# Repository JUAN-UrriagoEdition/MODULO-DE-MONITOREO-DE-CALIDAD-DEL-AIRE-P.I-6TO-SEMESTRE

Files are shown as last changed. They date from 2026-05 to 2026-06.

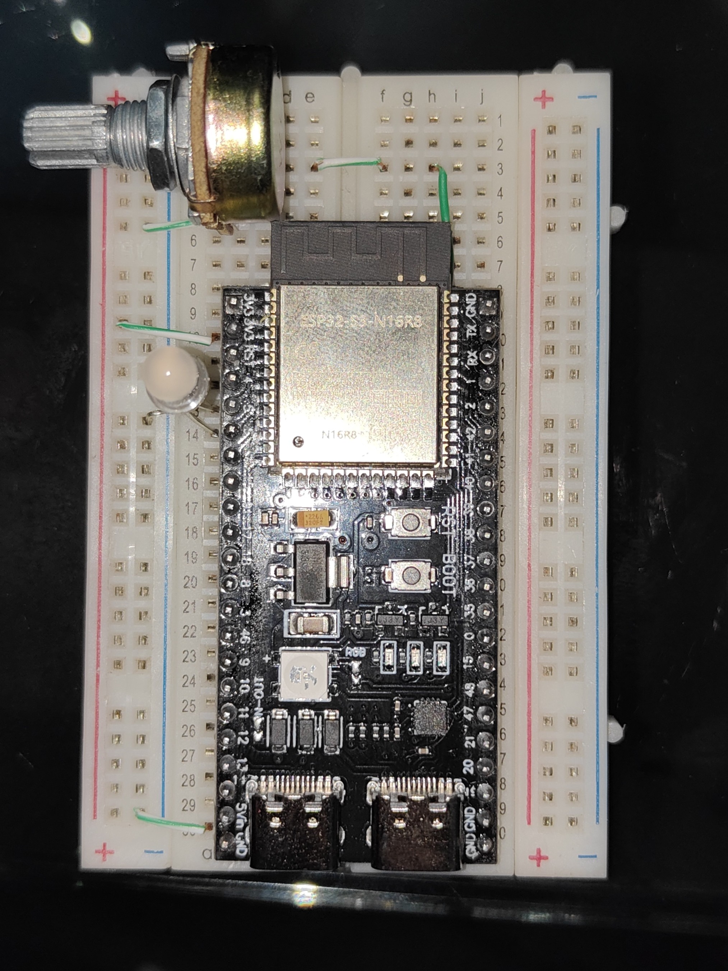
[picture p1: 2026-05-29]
Primer prototipo (Concepto).jpg

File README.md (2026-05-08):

# 🌬️ Estación Modular de Calidad del Aire (AQ)
### Módulo de Gases Electroquímicos — Ingeniería Electrónica, UCEVA 2026

<div align="center">






</div>

---

## 📋 Descripción General

Este repositorio documenta el **Módulo de Gases Electroquímicos** de la Estación Modular de Calidad del Aire (AQ), desarrollado como proyecto integrador de 6to semestre en la **Facultad de Ingeniería Electrónica de la Unidad Central del Valle del Cauca (UCEVA)**.

El módulo mide en tiempo real las concentraciones de **monóxido de carbono (CO)**, **dióxido de nitrógeno (NO₂)**, **CO₂ equivalente** y **compuestos orgánicos volátiles (COV)** tanto en entornos interiores como exteriores, publicando los datos a un dashboard web mediante WiFi.

> 📄 **[Descargar Informe Técnico Completo (WORD)](./ESTACION_AQ_ACTUALIZADO.docx)**
> 📄 **[Descargar Repositorio (.bat)](./Descargar_Repo_Monitor_de_Gases.bat)**

---

## 🎯 Motivación

La contaminación del aire representa uno de los mayores problemas de salud pública a nivel mundial. En el municipio de **Tuluá y el Valle del Cauca**, la ausencia de redes densas de monitoreo continuo limita la detección oportuna de episodios críticos de contaminación, especialmente en corredores viales de alto tráfico y en espacios interiores de instituciones educativas.

Los sistemas convencionales de monitoreo tienen costos de entre **USD 50.000 y 200.000** por estación. Este módulo propone una alternativa de **bajo costo** basada en sensores MEMS, con criterios rigurosos de instrumentación, calibración y validación.

---

## ⚙️ Arquitectura del Sistema

La cadena de instrumentación sigue el flujo completo:

```
Sensor MEMS → Filtro RC (fc ≈ 10.6 Hz) → Buffer LMV321 → ADC 12-bit ESP32-S3 → Procesamiento → WiFi → Hub → Dashboard
```

El sensor digital **CCS811** se conecta directamente por bus **I²C**, sin requerir acondicionamiento analógico externo.

---

## 🔬 Sensores y Componentes Principales

| Componente | Función | Interfaz |
|---|---|---|
| **SEN0564** (DFRobot) | CO — 5 a 5000 ppm | Analógica (0.4–2.0 V) |
| **SEN0574** (DFRobot) | NO₂ — 0.1 a 10 ppm | Analógica |
| **CCS811** (ScioSense) | CO₂eq + TVOC | Digital I²C |
| **ESP32-S3-WROOM-1U** | MCU, ADC 12-bit, WiFi | — |
| **LMV321** | Buffer seguidor de voltaje | — |
| **REF2033A** | Referencia de voltaje dual 3.3/1.65 V | — |
| **LP38692MP-3.3** | Regulador LDO 3.3 V | — |
| **LED RGB** | Indicación visual de calidad del aire | PWM |

---

## 📐 Diseño de Acondicionamiento Analógico

- **Filtro RC pasabajas** de primer orden: `R = 10 kΩ`, `C = 1.5 µF` → `fc ≈ 10.6 Hz`
- **Buffer LMV321** en configuración seguidor unitario (ganancia 1) para desacoplar la impedancia del ADC
- **Referencia REF2033A** con baja deriva térmica para estabilidad en la conversión ADC
- **ADC SAR de 12 bits** del ESP32-S3: resolución teórica de `≈ 0.806 mV/bit`
- **Sobremuestreo y promediado** (N = 32–64 muestras) para mejorar la resolución efectiva (ENOB ≥ 11 bits)

---

## 💡 Indicación Visual

El LED RGB indica el nivel de calidad del aire mediante colores controlados por PWM (5 kHz, 8 bits):

| Color | Estado | Umbral |
|---|---|---|
| 🟢 Verde | Limpio | < 40% de escala |
| 🟡 Ámbar | Advertencia | 40–70% de escala |
| 🔴 Rojo | Crítico | > 70% de escala |

---

## 📡 Formato de Mensajes JSON (Contrato de Datos)

El módulo publica al hub central mensajes con la siguiente estructura mínima:

```json
{
  "module": "gas_module_01",
  "environment": "indoor",
  "location": "UCEVA - Aula 201",
  "ts": 1745000000,
  "metrics": {
    "co_ppm": 1.2,
    "no2_ppm": 0.05,
    "eco2_ppm": 520,
    "tvoc_ppb": 35,
    "quality": "ok",
    "temp_comp": 24.5,
    "rh_comp": 58.0
  }
}
```

---

## 🔄 Estados del Firmware

| Estado | Descripción |
|---|---|
| `warmup` | Calentamiento inicial del sensor (< 2 min) |
| `ok` | Operación normal |
| `fault` | Sensor desconectado o señal fuera de rango |
| `saturation` | Señal en los extremos del rango ADC |
| `suspect` | Alta variabilidad o lecturas inconsistentes |

---

## 📦 Lista de Materiales (BOM)

Los componentes fueron adquiridos mediante el pedido **Mouser N.° 279751168** (enviado el 21 de abril de 2026). El costo total del pedido fue de aproximadamente **USD 48** más aranceles de importación colombianos.

Los sensores SEN0564, SEN0574 y el LED RGB se adquirieron de forma local/separada.

---

## 🧪 Pruebas y Criterios de Aceptación

| ID | Prueba | Criterio |
|---|---|---|
| CP01 | Rango analógico SEN0564 (CO) | V_out varía de forma monotónica en 0.4–2.0 V |
| CP04 | Respuesta del filtro RC | Atenuación a fc = −3 dB ± 1 dB; a 10·fc ≥ −20 dB |
| CP06 | Publicación de mensajes JSON | ≥ 5 mensajes válidos en 5 minutos |
| CP07 | Estado warmup al encender | `quality = warmup` durante ≥ 60 s |
| CP08 | Estado fault ante desconexión | `quality = fault` en ≤ 3 ciclos de publicación |

---

## 👥 Equipo

| Nombre | Código |
|---|---|
| David Ortega Ruiz | 240232001 |
| Juan Fernando Urriago Hernández | 240232002 |
| Sergio Peñaranda Agudelo | 240232004 |
| Miguel Ángel Parra Gutiérrez | 240232013 |

**Asignatura integradora:** Instrumentación I  
**Docente:** Álvaro Hernando Salazar Victoria  
**Facultad de Ingeniería Electrónica — UCEVA, 2026**

---

## 📚 Referencias Clave

- Mead et al. (2013) — *Atmospheric Environment* — Redes urbanas con sensores electroquímicos
- Kumar et al. (2015) — *Environment International* — Sensores de bajo costo para calidad del aire
- Spinelle et al. (2015) — *Sensors and Actuators B* — Calibración en campo con MLR
- Zimmerman et al. (2018) — *Atmospheric Measurement Techniques* — Calibración con Random Forest

---

> 📄 **[Descargar Informe Técnico Completo (PDF)](./ESTACIÓN_MODULAR_DE_CALIDAD_DEL_AIRE.pdf)**

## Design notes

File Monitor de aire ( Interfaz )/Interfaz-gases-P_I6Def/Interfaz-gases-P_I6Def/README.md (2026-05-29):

# Interfaz-gases P.I6Def — Monitor de Gases ESP32-S3
## Requisitos
- NetBeans IDE 17+ con soporte para proyectos Java Free-Form / Ant
- JDK 17 o superior
- ESP32-S3 corriendo el firmware P_I6Def_ESP32S3_fixed.ino
  (protocolo serial 115200 baud: CO:<ppm>,NO2:<ppm>,CO2:<ppm>,VOC:<ppb>)

---

## Abrir en NetBeans (primera vez)

1. File → Open Project → seleccionar esta carpeta (Interfaz-gases-P_I6Def)
2. NetBeans detecta el build.xml de Ant automáticamente
3. **Run → Build Project (F11)**
   - Ant descarga jSerialComm-2.11.0.jar automáticamente a lib/
   - Si no hay internet: descarga el JAR manualmente de
     https://github.com/Fazecast/jSerialComm/releases
     y cópialo a lib/jSerialComm-2.11.0.jar
4. **Run → Run Project (F6)** para ejecutar la GUI

---

## Si NetBeans no reconoce el classpath

Project Properties → Libraries → Add JAR/Folder → selecciona:
  lib/jSerialComm-2.11.0.jar

---

## Protocolo Serial (ESP32-S3 → Java)

Líneas de datos (parseadas por la GUI):
  CO:85.30,NO2:0.042,CO2:512.0,VOC:180.0

Líneas de log (ignoradas por la GUI, empiezan con #):
  # [OK] CCS811 listo
  # t=5s  Vco=1.234V  Vno2=2.987V

Baud rate: 115200
Terminador: \n

---

## Funciones de la GUI

- Indicadores circulares (gauges) con colores por nivel de alerta
- Gráficas históricas de los últimos 60 segundos
- Selector de puerto serial con botón de refresco
- Modo DEMO (simula datos sin hardware conectado)
- Estado de conexión en tiempo real

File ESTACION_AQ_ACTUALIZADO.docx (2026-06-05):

ESTACIÓN MODULAR DE CALIDAD DEL AIRE (AQ) PARA INTERIOR Y EXTERIOR

[MÓDULO DE GASES ELECTROQUÍMICOS]

David Ortega Ruiz — Código: 240232001

Miguel Ángel Parra Gutiérrez — Código: 240232013

Sergio Peñaranda Agudelo — Código: 240232004

Juan Fernando Urriago Hernández — Código: 240232002

Trabajo presentado para la asignatura integradora: Instrumentación I

Docente: SALAZAR VICTORIA ALVARO HERNANDO

Asignaturas que se articulan:

Administración — HERNANDEZ TRUJILLO YANIER ALBERTO

Electrónica Digital II — ARENAS HOYOS SERGIO ANDRES

Sistemas & Señales — LOZADA DAS DORES ANGEL JOSE

Circuitos Electrónicos II — PEREZ HERNANDEZ JAIME

Comunicaciones I — SALDARRIAGA VILLAFAÑE HAEDERS

Facultad de Ingeniería — Ingeniería Electrónica

Unidad Central del Valle del Cauca — 2026

# 1. INTRODUCCIÓN

## 1.1 Contexto del Problema (Calidad del Aire Indoor/Outdoor)

La contaminación atmosférica representa uno de los mayores problemas de salud pública a nivel mundial. Según la Organización Mundial de la Salud (OMS), alrededor de 7 millones de personas mueren prematuramente cada año como consecuencia directa de la exposición a aire contaminado en entornos tanto interiores como exteriores. En las zonas urbanas latinoamericanas, incluyendo el departamento del Valle del Cauca (Colombia), la combinación de emisiones vehiculares, actividad industrial y quema de biomasa genera concentraciones significativas de monóxido de carbono (CO) y dióxido de nitrógeno (NO₂), que en episodios de alta contaminación pueden superar los valores guía de la OMS y los límites establecidos por la Resolución 2254 de 2017 del MADS (Kumar et al., 2015).

Los sistemas de monitoreo convencionales tienen costos de adquisición e instalación en el rango de USD 50.000–200.000 por estación, lo que impide la construcción de redes de medición de alta densidad espacial. Esta limitación ha impulsado el desarrollo de sensores de bajo costo —electroquímicos y de óxidos metálicos semiconductores (MOX) tipo MEMS— capaces de proporcionar datos representativos cuando se diseñan e implementan con criterios rigurosos de instrumentación, calibración y validación de datos (Lewis & Edwards, 2016; Mead et al., 2013).

En el contexto local del municipio de Tuluá y sus alrededores, la carencia de redes densas de monitoreo continuo limita la capacidad de detección oportuna de episodios críticos de contaminación, especialmente en corredores viales de alto tráfico y en espacios interiores de instituciones educativas.

## 1.2 Motivación del Módulo

El módulo de gases es uno de los componentes centrales de la estación modular AQ propuesta. Los sensores seleccionados —SEN0564 para CO y SEN0574 para NO₂, ambos con tecnología MEMS de DFRobot— generan señales de voltaje analógico compatibles con el ADC del ESP32-S3-WROOM-1U directamente. El circuito de acondicionamiento incluye filtros RC pasabajas y seguidores de voltaje (LMV321) para garantizar lecturas estables. Los gases elegidos —CO y NO₂— son contaminantes de alta relevancia para la salud pública en entornos urbanos colombianos.

Adicionalmente, el módulo incorpora el sensor digital CCS811 para medición complementaria de CO₂ equivalente y COV (Compuestos Orgánicos Volátiles), comunicado por bus I²C con el ESP32-S3-WROOM-1U. Esta combinación permite una caracterización más completa de la calidad del aire interior.

# 2. PLANTEAMIENTO DEL PROBLEMA Y OBJETIVOS

## 2.1 Problema a Resolver

La ausencia de redes de monitoreo continuo y de bajo costo para gases contaminantes en las zonas urbanas del Valle del Cauca impide la detección, cuantificación y alerta oportuna de episodios de contaminación del aire en tiempo real. En espacios interiores prácticamente no existe monitoreo de CO y NO₂, pese a que diversas fuentes pueden generar concentraciones superiores a los valores guía de la OMS durante periodos prolongados.

El reto técnico central de este módulo es integrar los sensores MEMS SEN0564 y SEN0574 con el microcontrolador ESP32-S3-WROOM-1U, garantizando un acondicionamiento analógico adecuado (filtrado, buffer de impedancia), adquisición confiable por ADC de 12 bits, y comunicación inalámbrica de datos hacia el hub central del sistema AQ.

## 2.2 Objetivo General

Diseñar e implementar una estación modular AQ capaz de medir variables ambientales y contaminantes gaseosos (CO y NO₂), procesarlas digitalmente y publicarlas en un dashboard web con histórico y alertas, demostrando criterios de diseño de instrumentación (rango, resolución, filtrado, calibración y manejo de error), operando en interior y exterior.

## 2.3 Objetivos Específicos

- Seleccionar y caracterizar los sensores SEN0564 (CO), SEN0574 (NO₂) y CCS811 (CO₂eq/COV) para calidad del aire.
- Diseñar el acondicionamiento analógico con filtros RC y buffers LMV321 para llevar las señales al rango del ADC del ESP32-S3-WROOM-1U.
- Publicar datos mediante un esquema de comunicación IoT usando un formato estándar de mensajes JSON.
- Integrar todos los módulos en un sistema común (hub) con almacenamiento, alertas y dashboard web.
- Realizar calibración mínima y reportar un presupuesto básico de error.

# 3. ESTADO DEL ARTE

## 3.1 Referentes

### Sensores electroquímicos en redes urbanas densas (Mead et al., 2013)

El trabajo de Mead et al. (2013), publicado en Atmospheric Environment, es uno de los estudios fundacionales del monitoreo urbano de bajo costo. El equipo de la Universidad de Cambridge desplegó 14 nodos equipados con sensores electroquímicos para CO, NO₂ y O₃, y los comparó durante varios meses con analizadores de referencia certificados. Los resultados demostraron que los sensores electroquímicos son viables para detectar gradientes espaciales y temporales de contaminación, pero presentan sensibilidades cruzadas significativas a la temperatura, la humedad relativa y a gases interferentes. El estudio concluye que la compensación de temperatura y humedad en el firmware es indispensable para lograr coeficientes de correlación r² > 0.80 respecto a los instrumentos de referencia.

### Gestión de calidad del aire urbana con sensores de bajo costo (Kumar et al., 2015)

Kumar et al. (2015) realizaron una revisión exhaustiva del estado del arte en sistemas de sensores de bajo costo para monitoreo de calidad del aire urbana. Analizaron comparativamente las tecnologías disponibles —electroquímica, MOX, fotoionización (PID) y NDIR— en términos de sensibilidad, deriva temporal, efecto de la humedad relativa, costo y complejidad de calibración. Sus conclusiones identifican que la principal barrera de adopción de sensores de bajo costo no es la sensibilidad inicial, sino la deriva de calibración a largo plazo y el efecto de la humedad relativa sobre la respuesta del sensor.

### Calibración en campo de sensores de bajo costo (Spinelle et al., 2015)

Spinelle et al. (2015) publicaron los resultados de la calibración en campo de sensores de bajo costo para O₃ y NO₂ frente a instrumentos de referencia. Los experimentos demostraron que la incorporación de temperatura y humedad relativa como covariables en modelos de regresión lineal múltiple mejora el coeficiente de determinación R² de valores entre 0.30–0.50 a valores superiores a 0.85.

### Calibración con Random Forest (Zimmerman et al., 2018)

Zimmerman et al. (2018) propusieron el uso de modelos de aprendizaje automático (Random Forest) para la calibración de sensores de bajo costo de NO₂ y CO, demostrando que los modelos de bosque aleatorio logran R² superiores a 0.90 para NO₂ y reducciones del error cuadrático medio de hasta 40% respecto a la regresión lineal múltiple.

### Comparación de microsensores con métodos de referencia — EuNetAir (Borrego et al., 2016)

Borrego et al. (2016) presentaron el ejercicio comparativo europeo EuNetAir, donde sensores de bajo costo fueron evaluados simultáneamente contra instrumentos de referencia certificados en múltiples sitios de Europa. Los resultados confirmaron que los sensores de CO presentan el mejor desempeño relativo sin compensación ambiental, mientras que NO₂ muestra mayor variabilidad y dependencia de la humedad.

## 3.2 Comparación de Enfoques

Referente | Tecnología sensor | Acondicionamiento | Comunicación | Métrica de validación
Mead et al. (2013) | Electroquímica | TIA + offset + RC | ZigBee/3G | R² = 0.70–0.85 (con comp. T/HR)
Kumar et al. (2015) | MOX + electroquímica | Div. resistivo + buffer | WiFi/GSM | Identifica deriva y efecto HR
Spinelle et al. (2015) | Electroquímica (O₃/NO₂) | Buffer + MLR (T,HR) | USB/LAN | R² > 0.85 con MLR
Zimmerman et al. (2018) | MOX + electroquímica | Buffer + RF-ML | Ethernet | R² > 0.90 con Random Forest
Borrego et al. (2016) | Electroquímica/MOX | TIA + buffer | LAN | CO mejor desempeño sin comp.
Lewis & Edwards (2016) | Múltiples | Variados | Variados | r² ≥ 0.70, sesgo < 30%

## 3.3 Lecciones Aprendidas

- Compensación de temperatura y humedad es indispensable: todos los referentes señalan que T y HR afectan significativamente las lecturas. El módulo solicitará estos valores al módulo meteorológico del sistema y los incluirá en el campo metrics del mensaje JSON.
- El buffer de impedancia (seguidor de voltaje con LMV321) es la etapa crítica para la lectura confiable de los sensores MEMS tipo SEN0564 y SEN0574, cuya salida analógica requiere aislamiento de la carga del ADC.
- Priorizar el canal de CO para validación inicial: los sensores de CO presentan el mejor desempeño relativo sin compensación ambiental.

# 4. MARCO TEÓRICO

## 4.1 Conceptos de Calidad del Aire Relevantes al Módulo

La calidad del aire se evalúa cuantitativamente mediante la concentración de contaminantes primarios y secundarios expresada en µg/m³ o ppm (partes por millón en volumen). Para los gases del módulo, los valores guía de la OMS (2021) y los límites de la normativa colombiana (Resolución 2254/2017) son:

Gas | Valor guía OMS (2021) | Límite Colombia (Res. 2254/2017) | Fuentes principales | Efecto en salud
CO | 4 mg/m³ (24h); 35 mg/m³ (1h) | 30 mg/m³ (1h); 10 mg/m³ (8h) | Combustión incompleta (vehículos, estufas) | Forma COHb; reduce transporte O₂
NO₂ | 25 µg/m³ (24h); 200 µg/m³ (1h) | 200 µg/m³ (1h); 100 µg/m³ (24h) | Combustión a alta T, motores, industria | Inflamación bronquial; precursor O₃
CO₂eq/COV | N/A (indicador interior) | N/A | Actividad humana, materiales sintéticos | Calidad del aire interior; síntomas de SBS

## 4.2 Principio Físico/Químico de los Sensores

### SEN0564 — Sensor CO (DFRobot, tecnología MEMS)

El SEN0564 es un sensor de monóxido de carbono basado en tecnología MEMS (Micro-Electro-Mechanical Systems) con salida analógica de voltaje. Internamente emplea un elemento semiconductor calentado que varía su resistencia eléctrica en presencia de CO. A diferencia de los módulos MQ-7 tradicionales, el SEN0564 incorpora el circuito de acondicionamiento interno, entregando directamente una señal de voltaje proporcional a la concentración de CO en el rango de 5 a 5000 ppm. La salida opera entre 1V (aire limpio) y 3.5 V (concentración máxima).

### SEN0574 — Sensor NO₂ (DFRobot, tecnología MEMS)

El SEN0574 es un sensor de dióxido de nitrógeno también basado en tecnología MEMS con salida analógica de voltaje, diseñado para detectar concentraciones de NO₂ en el rango de 0.1 a 10 ppm. Su principio de operación se basa en la variación de conductancia de un material semiconductor en función de la concentración del gas objetivo. La señal de salida es analógica y varía con la concentración de NO₂, con respuesta que depende de la temperatura y la humedad relativa del entorno, por lo que se requiere compensación en firmware.

### CCS811 — Sensor digital CO₂eq/COV

El CCS811 es un sensor digital de calidad del aire interior que mide CO₂ equivalente (eCO₂) y Compuestos Orgánicos Volátiles (COV o TVOC). Se comunica con el ESP32-S3-WROOM-1U mediante bus I²C, simplificando la integración al no requerir conversión analógico-digital ni circuito de acondicionamiento externo. Incorpora un microcontrolador interno que ejecuta el procesamiento de señal y entrega directamente los valores en ppm de eCO₂ y ppb de TVOC.

## 4.3 Conceptos Base de Instrumentación del Módulo

El seguidor de voltaje (buffer) implementado con el amplificador LMV321 cumple la función de adaptar la impedancia de salida de los sensores SEN0564 y SEN0574 a la impedancia de entrada del ADC del ESP32-S3-WROOM-1U. Sin este buffer, la carga capacitiva y resistiva del ADC puede alterar la lectura de los sensores, especialmente durante el proceso de muestreo del convertidor SAR. El LMV321 opera en configuración de seguidor unitario (ganancia 1), con rail-to-rail de salida, lo que lo hace adecuado para señales que cubren todo el rango de alimentación de 3.3V.

## 4.4 Fundamentos de Filtros Analógicos

Los sensores MEMS de gases presentan dinámicas lentas de respuesta: el tiempo de respuesta t₉₀ del SEN0564 y SEN0574 es del orden de decenas de segundos. Esto implica que el contenido frecuencial de la señal de interés está por debajo de fracciones de Hz. Todo contenido espectral por encima de esta frecuencia corresponde a ruido eléctrico y debe atenuarse antes de la conversión ADC.

Se implementa un filtro RC de primer orden pasivo a la salida de cada sensor, antes del buffer LMV321. Con R = 10 kΩ y C = 1.5 µF, la frecuencia de corte resulta fc ≈ 10.6 Hz. Esta topología conserva la dinámica lenta del gas y atenúa perturbaciones rápidas asociadas al ruido, siendo suficiente para una etapa de adquisición de baja velocidad como la de este módulo.

# 5. REQUISITOS Y CRITERIOS DE ACEPTACIÓN

## 5.1 Requisitos Funcionales

ID | Requisito Funcional | Prioridad
RF-01 | El módulo medirá CO con el sensor SEN0564 (DFRobot MEMS) en el rango 5–5000 ppm mediante señal analógica de voltaje y ADC de 12 bits del ESP32-S3-WROOM-1U. | Alta
RF-02 | El módulo medirá NO₂ con el sensor SEN0574 (DFRobot MEMS) en el rango 0.1–10 ppm mediante señal analógica de voltaje y ADC. | Alta
RF-03 | El módulo leerá CO₂eq y TVOC del sensor digital CCS811 mediante bus I²C con el ESP32-S3-WROOM-1U. | Media
RF-04 | El circuito de acondicionamiento garantizará que la señal de salida de todos los canales analógicos se encuentre en el rango 0.1–3.3 V para el ADC. | Alta
RF-05 | Cada canal analógico contará con un filtro RC pasabajas (fc ≈ 10.6 Hz) y buffer LMV321 antes de la entrada ADC. | Alta
RF-06 | El ADC del ESP32-S3-WROOM-1U adquirirá señales a una tasa de muestreo fs ≥ 10 Hz con resolución de 12 bits. | Media
RF-09 | El módulo operará en dos modos: indoor (publicación cada 10–30 s) y outdoor (publicación cada 30–60 s). | Media
RF-10 | El firmware gestionará los estados del sensor: warmup, ok, fault, saturation, suspect. | Alta
RF-11 | El sistema implementará indicación visual de nivel de contaminación mediante LED RGB: verde (limpio), ámbar (advertencia) y rojo (crítico). | Media

## 5.2 Requisitos No Funcionales

ID | Requisito | Valor objetivo
RNF-01 | Frecuencia de publicación — indoor | Cada 10–30 s
RNF-02 | Frecuencia de publicación — outdoor | Cada 30–60 s (con promedio de ventana extendida)
RNF-03 | Tiempo de warm-up hasta primer dato ok | < 5 minutos desde el encendido
RNF-04 | Tensión de alimentación del módulo | 5 V entrada y sensores; 3.3 V regulado (LP38692MP-3.3) para ESP32-S3-WROOM-1U, LMV321
RNF-05 | Rango de temperatura de operación outdoor | 0°C a +50°C
RNF-06 | ENOB efectivo mínimo con promediado | ≥ 11 bits (N = 64 muestras, oversampling)
RNF-07 | Comportamiento ante pérdida de conectividad | Almacenamiento local y reenvío al reconectar
RNF-09 | Protección contra saturación del ADC | El acondicionamiento analógico mantiene la señal dentro del rango 0–3.3 V

## 5.3 Criterios de Aceptación Preliminares

- Acondicionamiento analógico: la señal de salida permanecerá entre 0.1 V y 3.3 V para todas las concentraciones de gas dentro del rango nominal del sensor.
- Filtro analógico: se demostrará una atenuación ≥ 6 dB a una frecuencia 10 veces superior a la fc de diseño.
- Publicación de mensajes: el módulo publicará al menos 5 mensajes JSON válidos al hub durante una sesión de prueba de 5 minutos.
- Indicación visual: el LED RGB cambiará de color de forma consistente con el nivel de contaminación detectado por el potenciómetro de simulación o el sensor real.

6. SELECCIÓN Y CARACTERIZACIÓN DEL SENSOR

## 6.1 Principio de Medición

El módulo de gases emplea tres sensores con principios de medición complementarios. El SEN0564 y SEN0574 (DFRobot) utilizan tecnología MEMS con salida analógica de voltaje, mientras que el CCS811 emplea tecnología digital con interfaz I²C.

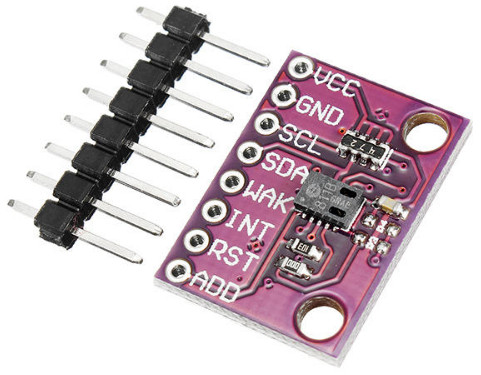
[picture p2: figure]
CJMCU-811 - RevSpace
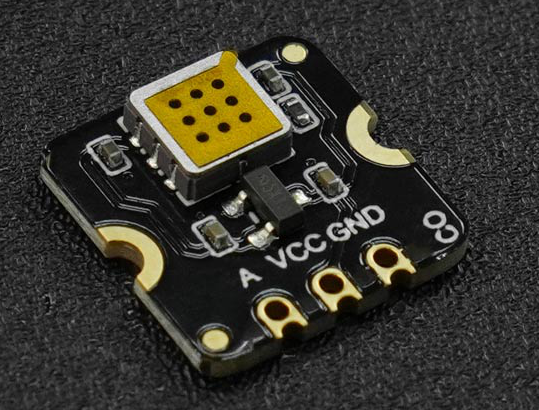
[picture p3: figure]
SEN0564 - Sigma Electrónica

Ilustración 3 CSS 811 - SENSOR DE GASES VOLATILES

Ilustración 2 SEN0574 - SENSOR NO2

Ilustración 1 SEN0564 - SENSOR DE CO

## 6.2 Rango Esperado y Sensibilidad

Parámetro | SEN0564 (CO — MEMS) | SEN0574 (NO₂ — MEMS) | CCS811 (CO₂eq/COV — digital)
Gas objetivo | CO | NO₂ | CO₂ equivalente + TVOC
Principio físico | Semiconductor MEMS — salida analógica | Semiconductor MEMS — salida analógica | MOx — salida digital I²C
Rango de medición | 5–5000 ppm (CO) | 0.1–10 ppm (NO₂) | 400–29206 ppm eCO₂; 0–32768 ppb TVOC
Señal de salida | Voltaje analógico 1.0–3.5 V | Voltaje analógico (proporcional) | Digital I²C (registros de 16 bits)
Tensión de operación | 5 V | 5 V | 1.8–3.6 V (I²C a 3.3 V)
Temperatura de operación | 0°C a +50°C | 0°C a +50°C | −40°C a +85°C
Tiempo de respuesta | < 30 s | < 30 s | < 60 s (modo 1s)
Tiempo de warm-up | 5 min | 5 min | 20 min (primer arranque); 60 s (subsiguientes)
Interferencias | Alcohol, LPG, humo | CO, O₃, H₂S | Temperatura, humedad

## 6.3 Fuentes de Error e Interferencias

- Temperatura y humedad (todos los sensores): la sensibilidad de los sensores MEMS varía con estas dos variables. Se implementará compensación mediante los datos del módulo meteorológico del sistema AQ.
- Interferencias cruzadas del SEN0574: el sensor de NO₂ puede ser afectado por presencia de CO, O₃ y H₂S en concentraciones elevadas.
- Warm-up del CCS811: el sensor requiere un tiempo de calentamiento de 20 minutos en el primer arranque para estabilizar su respuesta. El firmware reportará estado warmup durante este periodo.

## 6.4 Consideraciones Indoor vs Outdoor

Aspecto | Indoor (Interior) | Outdoor (Exterior)
Conc. típicas CO | 1–10 ppm (cocina, calefacción) | 0.1–5 ppm (tráfico urbano)
Conc. típicas NO₂ | 0.05–0.5 ppm (cocina gas, tráfico exterior) | 0.05–0.5 ppm (urbano); >1 ppm (vial alta densidad)
Efecto de humedad | Más estable, HR típica 40–60% | HR puede llegar a 90–100%
Temperatura | Más estable (18–28°C) | Mayor rango (5–40°C); exposición solar posible
Umbrales de alerta | Más sensibles (OMS ×1) | Umbrales según normativa outdoor (OMS/EPA)
Frecuencia de publicación | Cada 10–30 s | Cada 30–60 s (promedio ventana extendida)
Acciones outdoor | N/A | Caja con protección IP54; rejillas anti-insectos; shield solar

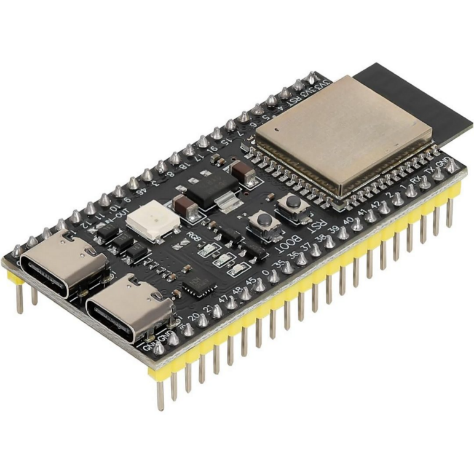
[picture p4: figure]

Ilustración 4 ESP32-S3 - Microcontrolador del módulo. Incluye ADC de 12 bits, WiFi, Bluetooth y soporte para FreeRTOS

# 7. ARQUITECTURA DEL SISTEMA Y DIAGRAMA DE BLOQUES

## 7.1 Diagrama de Bloques del Módulo

La arquitectura del módulo sigue la cadena de instrumentación completa: los sensores SEN0564 y SEN0574 generan señales analógicas de voltaje que pasan por un filtro RC pasabajas (R = 10 kΩ, C = 1.5 µF), luego por un buffer seguidor de voltaje (LMV321), y finalmente ingresan a los pines ADC del ESP32-S3-WROOM-1U. El sensor CCS811 se conecta directamente por I²C.

Ilustración 5 Diagrama de bloques del módulo de gases — Sensor → Filtro RC → Buffer LMV321 → ADC ESP32-S3-WROOM-1U → Procesamiento → WiFi → Hub

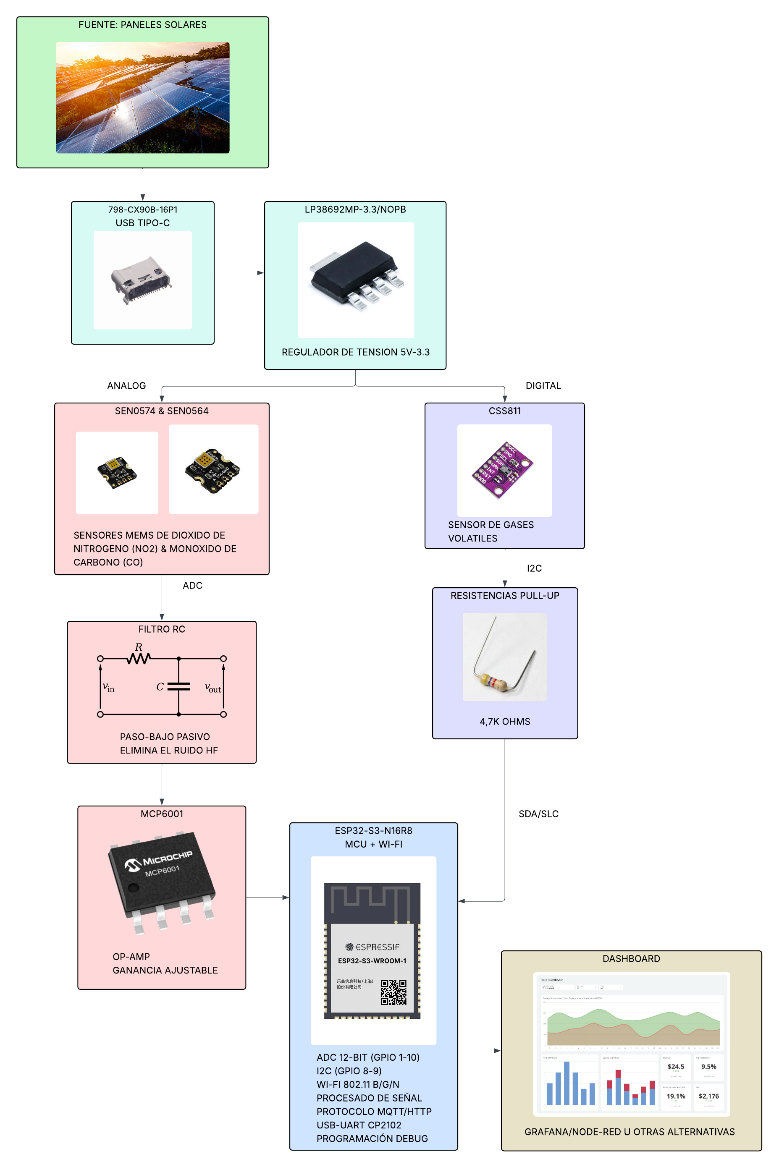
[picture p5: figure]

## 7.2 Integración con el Sistema Común

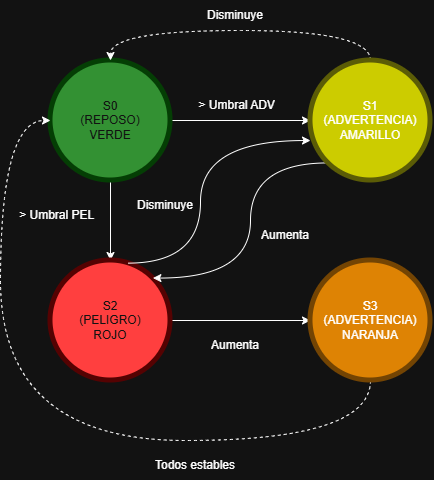
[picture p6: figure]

El módulo opera como un nodo de medición autónomo que se conecta al hub central mediante WiFi. El hub recibe los mensajes JSON, los almacena en la base de datos y los envía al dashboard web para visualización en tiempo real e histórico.

Ilustración 6 Diagrama de flujo

## 7.3 Contrato de Datos Inicial

Los campos mínimos del mensaje JSON a enviar al hub son: module (identificador del módulo), environment (indoor/outdoor), location (coordenadas o nombre), ts (timestamp Unix), y metrics con los campos: co_ppm, no2_ppm, eco2_ppm, tvoc_ppb, quality, temp_comp, rh_comp.

# 8. PLAN DE PRUEBAS INICIAL

## 8.1 Instrumentos y Método de Prueba

Instrumento / Material | Uso en las pruebas | Disponibilidad
Multímetro digital (Fluke 117 o similar) | Medición de voltajes DC en etapas de acondicionamiento | Laboratorio
Fuente DC regulada (0–30 V, 3 A) | Alimentación del protoboard durante pruebas | Laboratorio
Encendedor de butano (fuente de CO) | Generación de CO para prueba de respuesta del SEN0564 | Fácil adquisición
Monitor serial (Arduino IDE / PuTTY) | Verificación de datos ADC y mensajes JSON en tiempo real | PC laboratorio
LED RGB + potenciómetro | Simulación de señal de sensor y verificación de indicación visual | Disponible

## 8.2 Casos de Prueba y Criterios de Aceptación

ID | Caso de prueba | Procedimiento | Criterio de aceptación
CP-01 | Rango de salida analógica (SEN0564 CO) | Acercar fuente de CO y medir V_out con multímetro. | V_out varía de forma monotónica en el rango 1V–3.5V.
CP-02 | Rango de salida analógica (SEN0574 NO₂) | Exponer a fuente de NO₂ y medir V_out. | V_out varía en correspondencia con la concentración esperada.
CP-03 | Lectura I²C del CCS811 | Ejecutar firmware y verificar en monitor serial los valores de eCO₂ y TVOC. | Valores plausibles de eCO₂ (400–1000 ppm en aire limpio) y TVOC reportados.
CP-04 | Respuesta del filtro analógico RC | Inyectar señal sinusoidal a fc y a 10·fc. Medir atenuación. | Atenuación a fc = −3 dB ± 1 dB. Atenuación a 10·fc ≥ −20 dB.
CP-05 | Indicación visual LED RGB | Variar potenciómetro de simulación y observar color del LED. | Verde (< 40%), ámbar (40–70%), rojo (> 70%) de forma consistente.
CP-06 | Publicación de mensajes JSON | Ejecutar firmware y verificar en monitor serial el formato de mensajes. | ≥ 5 mensajes JSON válidos en 5 minutos, todos los campos presentes.

## 8.3 Riesgos y Mitigación

Riesgo identificado | Probabilidad | Impacto | Estrategia de mitigación
No-linealidad del ADC del ESP32-S3-WROOM-1U | Media | Media | Implementar tabla de corrección en firmware o usar solo el rango central (10–90%) del ADC.
Interferencia cruzada SEN0574 (NO₂ con CO) | Alta | Media | Documentar las limitaciones claramente. Reportar como índice relativo.
Warm-up del CCS811 excesivo (20 min primer arranque) | Alta | Baja | Reportar estado warmup en la interfaz. Mantener módulo energizado en operación continua.
Ruido en las líneas de señal analógica | Media | Media | Filtros RC en cada canal + buffer LMV321 + ruteo cuidadoso en PCB.
Pérdida de conectividad WiFi | Media | Baja | Implementar cola de almacenamiento local en SPIFFS del ESP32-S3-WROOM-1U.

# 9. DISEÑO DEL ACONDICIONAMIENTO DE SEÑAL

El presente avance consolida el diseño electrónico del módulo de gases a partir de los esquemáticos definidos. La arquitectura integra tres bloques: alimentación y regulación de 5 V a 3.3 V, adquisición digital del sensor CCS811 mediante I²C, y dos canales analógicos acondicionados para los sensores SEN0564 (CO) y SEN0574 (NO₂).

## 9.1 Esquemático por Etapas

La etapa de alimentación recibe 5 V desde la entrada principal, pasa por un regulador lineal LP38692MP-3.3, que entrega 3.3V para el resto del circuito. Se agregan capacitores de desacoplo cerámicos (22 µF y 0.1 µF) en la entrada y la salida para mejorar la estabilidad del regulador y reducir transitorios.

En la parte digital, el sensor CCS811 se conecta al ESP32-S3-WROOM-1U por I²C. Las líneas SDA y SCL poseen resistencias pull-up de 4.7 kΩ hacia 3.3 V al igual que los pines RESET e INT, mientras que WAKE enruta de forma controlada. En los canales analógicos, las salidas de los sensores SEN0564 y SEN0574 pasan por un divisor de voltaje para escalar los voltajes máximos de los sensores a 3.3V para que no dañen en ADC de la ESP32, luego pasan por un seguidor de tensión para acople de impedancias y una red RC de primer orden y finalmente por otro seguidor de voltaje, ambos seguidores se implementan con Op. Amps LMV321IDCKT. Esta estrategia evita la carga directa del ADC, reduce ruido de alta frecuencia y permite una lectura más consistente.

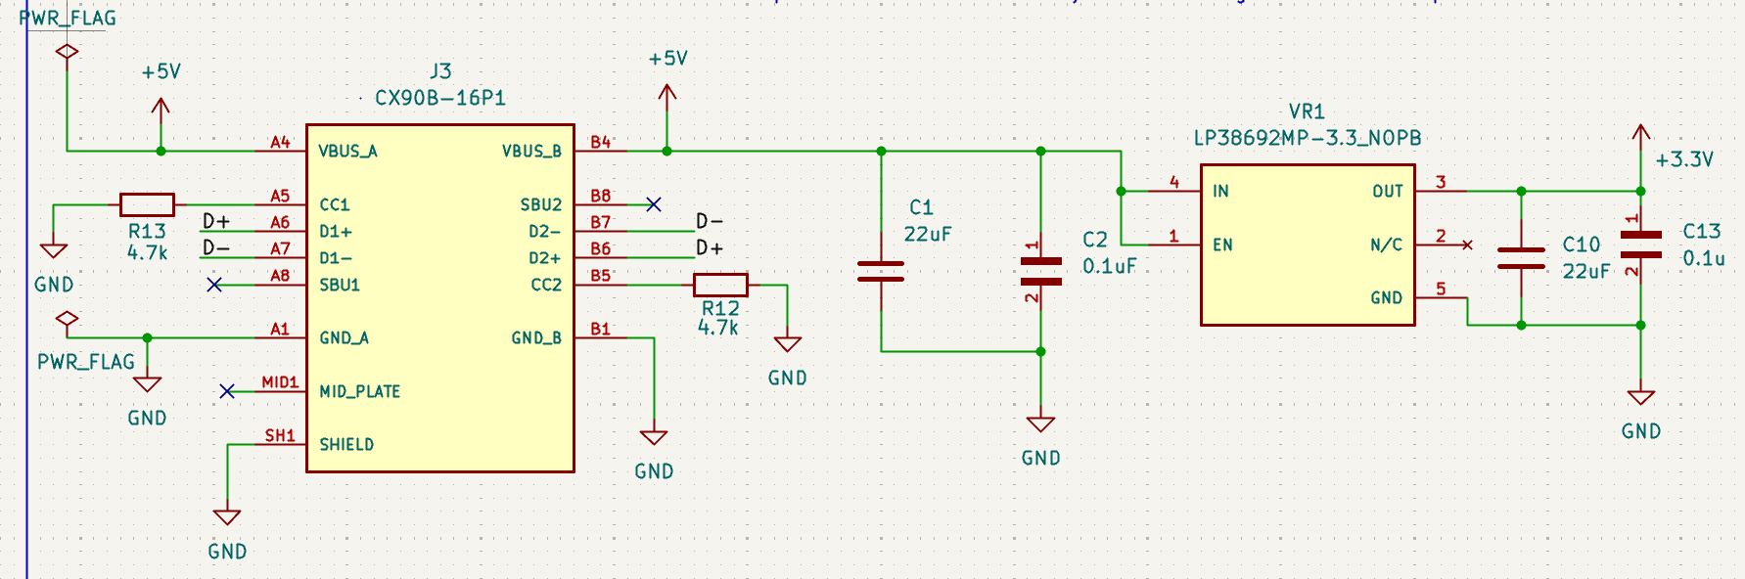
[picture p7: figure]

Ilustración 7 Etapa de alimentación y regulación de 5 V a 3.3 V con LP38692MP-3

## 9.2 Cálculos de Diseño

Elemento | Valor | Cálculo | Resultado
Filtro RC — canales CO (SEN0564) y NO2 (SEN0574) | R=10 kΩ, C=1.5 µF | fc = 1/(2πRC) | fc ≈ 10.6 Hz
Pull-up I²C (CCS811) | R=4.7 kΩ, V=3.3 V | I = V/R | I ≈ 0.70 mA
ADC ESP32-S3-WROOM-1U | 0–3.3 V, 12 bits | LSB = 3.3/4095 | ≈ 0.806 mV/bit
Buffer (LMV321) | Ganancia unitaria | Vo = Vi | Impedancia de salida baja, sin carga al sensor

## 9.3 Justificación de Decisiones de Diseño

El seguidor con LMV321 desacopla la salida del filtro de la impedancia del ADC y mejora la repetibilidad de la lectura. La regulación a 3.3 V con LP38692MP-3.3 unifica la electrónica digital y los sensores de baja potencia.

# 10. DISEÑO DE FILTROS ANALÓGICOS

## 10.1 Tipo de Filtro

Se implementaron filtros pasabajas RC de primer orden con buffer en las rutas analógicas de CO y NO₂. La topología RC con seguidor de voltaje es suficiente para esta etapa de adquisición de baja velocidad. Su función es atenuar ruido de alta frecuencia y evitar que el ADC reciba oscilaciones que no representan cambios reales en la concentración del gas.

## 10.2 Frecuencia de Corte y Justificación

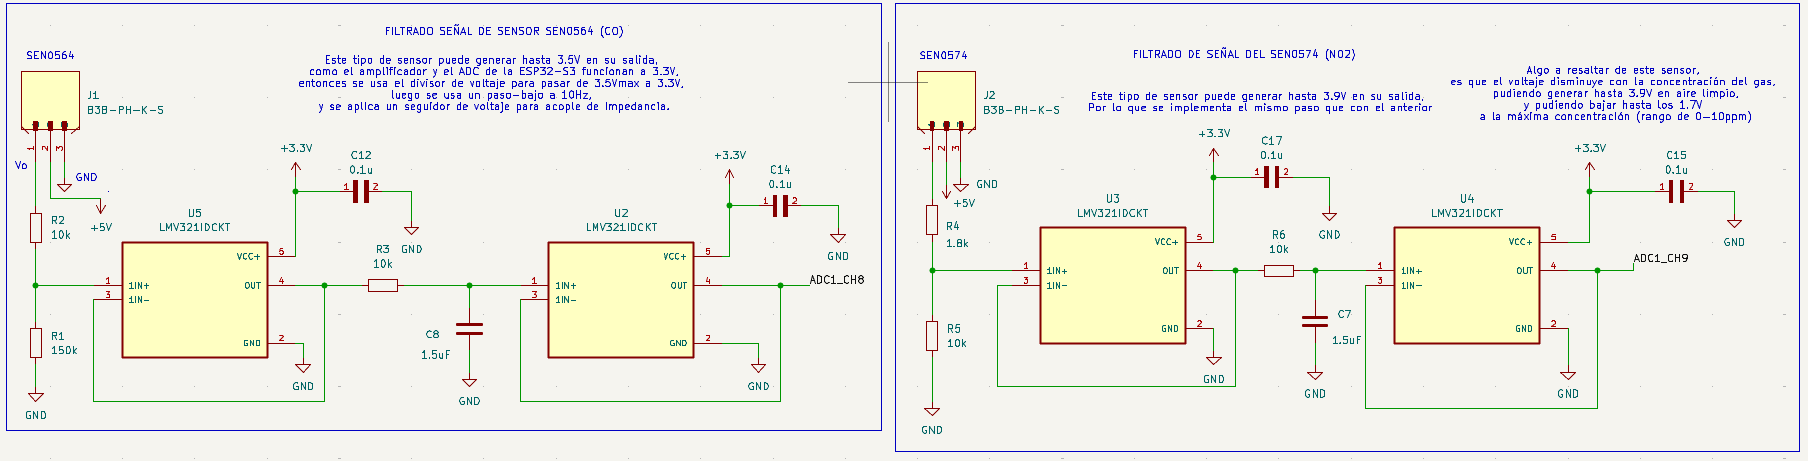
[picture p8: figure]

Con fc ≈ 10.6 Hz, la señal útil de los sensores MEMS (cuya dinámica es de decenas de segundos) conserva su forma. A frecuencias 10 veces superiores a fc (≈ 106 Hz), el filtro provee al menos −20 dB de atenuación, cumpliendo el criterio mínimo de diseño.

Ilustración 8 Filtros RC y buffers LMV321 para los sensores SEN0564 (CO) y SEN0574 (NO₂).

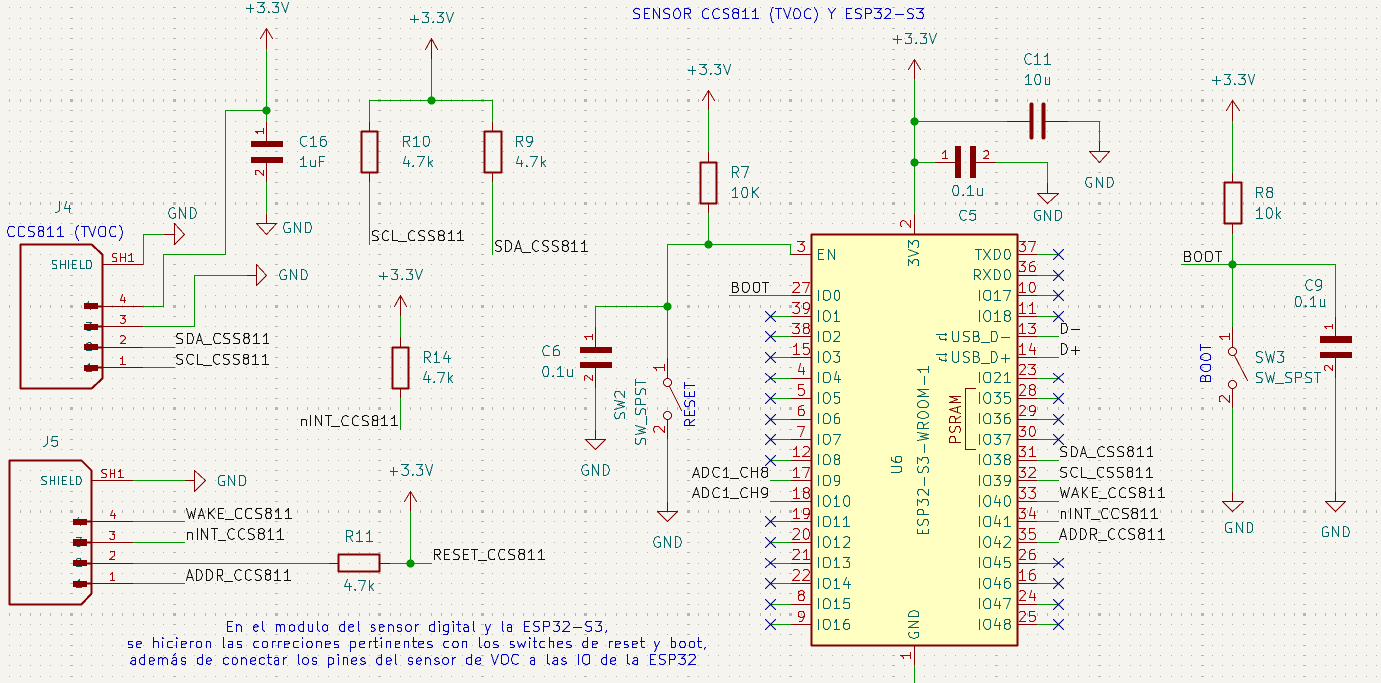
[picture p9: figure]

Ilustración 9 Interfaz digital del sensor CCS811 con el ESP32-S3-WROOM-1U por I²C

# 11. IMPLEMENTACIÓN DEL PROTOTIPO

## 11.1 Montaje y Consideraciones de Ruido/Tierras/Alimentación

El prototipo se implementó sobre protoboard con el ESP32-S3-WROOM-1U centrado en la placa como eje de conexión de todos los periféricos. Se separaron visualmente las rutas de alimentación (rieles de la protoboard) de las líneas de señal analógica, y se mantuvieron cortas las conexiones hacia los pines ADC para minimizar la captación de ruido.

Para la simulación de los sensores analógicos se implementó el circuito en protoboard tal como se diseñó en Kicad, con los sensores alimentados con 5V. La única diferencia es que se reemplazaron los Op. Amps del esquema por KIA358 alimentados a 5V y GND ya que no se podían conseguir operacionales rail-to-rail para protoboard, y usar un amplificador común a 3.3V no permitía ver los voltajes máximos de los sensores. Este enfoque permitió verificar el comportamiento del firmware y del sistema de indicación visual antes de integrar el sensor real.

Del sensor digital CCS811 solo usamos sus pines fundamentales para simplificar la programación (VCC, GND, SCL, SDA), y en cuanto al microcontrolador se dejó sin el montaje de los interruptores BOOT y RESET ya que venían integrados en la placa de la ESP32.

## 11.2 Problemas Encontrados y Correcciones

Durante el montaje inicial se detectó inestabilidad en las lecturas del ADC cuando el potenciómetro se posicionaba en los extremos de su recorrido (voltaje muy cercano a 0 V o a 3.3 V). Esto se corrigió limitando el rango de operación útil del potenciómetro en firmware (rango de mapeo seguro), y confirmando que el cable de conexión entre el cursor del potenciómetro y el pin ADC se mantenía lo más corto posible para reducir la antena de ruido.

También se presentó una leve variación del color del LED RGB al cambiar rápidamente entre estados, debida a la inercia visual del ojo humano ante transiciones abruptas de PWM. Se consideró añadir un fundido suave en firmware entre colores, aunque para el prototipo actual la transición directa fue suficiente para la demostración funcional.

## 11.3 Evidencias del Prototipo

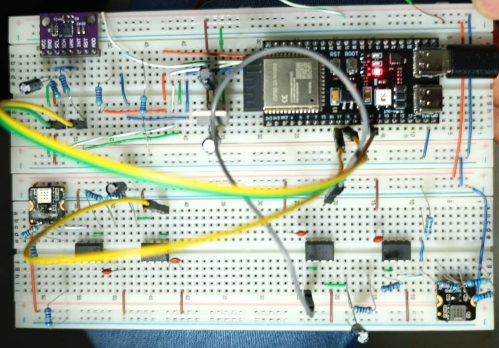
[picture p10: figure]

La Figura 5 muestra el estado actual del prototipo sobre protoboard: el ESP32-S3-WROOM-1U-N16R8, con antena IPEX externa está montada en la parte superior derecha de la protoboard, el sensor CCS811 está ubicado en la esquina superior izquierda junto a sus resistencias de pull-up el LED RGB en la zona derecha, y el botón pulsador integrado en la misma protoboard. Las conexiones de alimentación (3.3 V y GND) se distribuyeron por los rieles laterales de la placa.

Ilustración 10 Fotografía del prototipo sobre protoboard — ESP32-S3-WROOM-1U con potenciómetro de simulación de NO₂, LED RGB de indicación y pulsador de control

El monitor serial del IDE de Arduino muestra en tiempo real el porcentaje de contaminación simulada y el estado correspondiente (LIMPIO, ADVERTENCIA o CRITICO), confirmando el correcto funcionamiento del firmware y la cadena de lectura ADC → procesamiento → indicación visual.

# 12. ADQUISICIÓN CON ESP32-S3-WROOM-1U

## 12.1 Configuración del ADC

El ESP32-S3-WROOM-1U lee la señal del potenciómetro (simulando el sensor SEN0574 de NO₂) mediante su ADC interno de 12 bits en el pin GPIO1. La resolución del ADC proporciona 4096 niveles de cuantización en el rango de 0 a 3.3 V. El firmware realiza la lectura mediante la función analogRead() en cada ciclo del loop, con una cadencia de 500 ms entre lecturas para el prototipo de simulación.

# 15. Diseño PCB

En la siguiente imagen se muestra la PCB diseñada e implementada por el equipo de trabajo, en el cuadrante central superior se halla el conector de 5V que alimenta a los sensores y el regulador, justo en frente vemos dicho regulador de 3.3V el cual reparte ese potencial en todas direcciones, para proveer de potencia a los circuitos de acondicionamiento analógico (Op. Amps), el sensor digital CCS811 y el microcontrolador.

# A los costados de la PCB se halla el acondicionamiento junto a los conectores donde irían los sensores SEN0564 y SEN0574 en la parte inferior están los interruptores de Boot y Reset, junto a la ESP32-S3 y los conectores del CCS811.

El proceso de diseño ocurrió dentro de los parámetros, tuvimos cuidado de que no hubiese cortos en el layout, procuramos tener unos buenos planos de tierra separados por etapas, pistas y vías con el ancho indicado, junto a otros detalles de diseño como el uso de capacitores de desacoplo junto a cada integrado, en la capa inferior hubo pocos trazos y todos los componentes se ubicaron en la capa frontal.

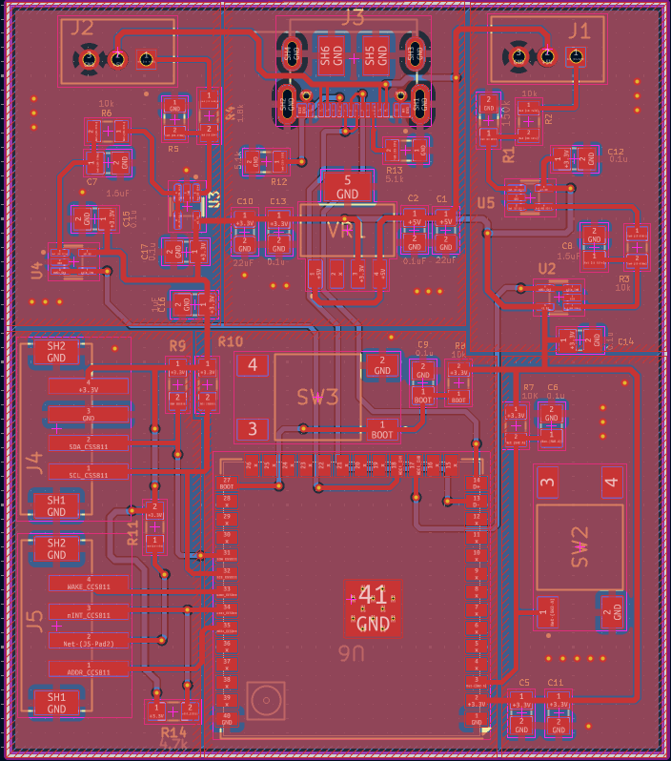
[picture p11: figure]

La etapa más difícil fue el proceso de soldadura, una vez tuvimos el stencil y las PCB nos aseguramos de medir continuidad en cada pista, observar que no hubiesen manchas de cobre donde no debían, que estuviese la serigrafía y espacio para cada cosa, tras esto, procedimos a colocar el stencil sobre la placa, untar la pasta de soldar, y quitar el stencil para poner cada componente en su sitio en un proceso que tomó bastante tiempo, pulso, y paciencia, para finalmente someter la tarjeta a la alta temperatura del horno.

La única situación problemática que hubo fue después de soldar, cuando la placa salió del horno y la conectamos, no funcionó como debía, ya que al conectarla a un PC este no reconocía al dispositivo, y después de tomar en cuenta aspectos como alimentación, microcontrolador dañado y observar las pistas, nos dimos cuenta que el problema era que las pistas de datos (D+ y D-) que salían del cargador y llegaban hasta la ESP estaban en corto, debido a la gran cantidad de estaño suministrada antes de hornear la tarjeta. Por lo que debimos desoldar el módulo conector, limpiar el exceso de pasta, verificar que dichos trazos estuviesen separados y finalmente volver a pegar el cargador, tras esto, volvimos a conectar la PCB a un PC y efectivamente, el IDE ya reconocía a nuestro prototipo y permitía la carga de código, estaba lista para usar.

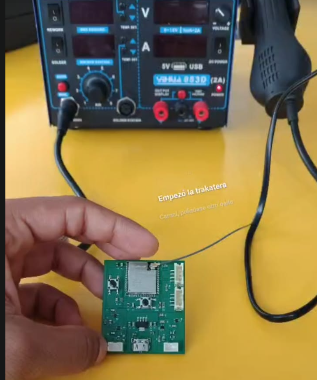
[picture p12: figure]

# Obviamente hay algunas cosas a tener en cuenta en el proceso de diseño, para más adelante, como poner leds indicadores para hacer diagnósticos más fáciles y verificar el funcionamiento correcto del sistema, que habilitásemos más puertos al microcontrolador para conexiones futuras de periféricos

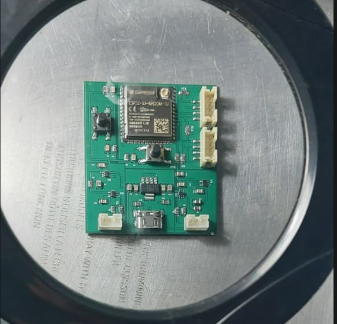
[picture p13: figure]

# 16. Comunicación e integración

El sistema P.I6Def implementa una arquitectura cliente-servidor en red local WiFi. El nodo sensor (ESP32-S3) actúa como servidor HTTP embebido y los hubs (GUI de escritorio y app Android) actúan como clientes que realizan peticiones periódicas.

Capa | Componente | Protocolo | Rol
Sensores | GM-702B (CO) GM-102B (NO₂) CCS811 (CO₂/VOC) | ADC 12-bit / I2C | Adquisición analógica y digital
Nodo | ESP32-S3-WROOM-1 | WiFi 802.11n | Procesamiento + servidor HTTP
Hub (Desktop) | PC + GUI Java (NetBeans) | HTTP GET / JSON | Visualización + historial
Hub (Móvil) | App Android (Java) | HTTP GET / JSON | Monitoreo remoto + notificaciones

Flujo de datos:

- Los sensores GM-702B y GM-102B entregan señales analógicas al ADC del ESP32-S3 (12 bits, atenuación 11 dB, rango 0–3.3 V).
- El sensor CCS811 se comunica con el ESP32-S3 por I2C (SDA→GPIO39, SCL→GPIO38) a dirección 0x5A, entregando eCO₂ y TVOC mediante el algoritmo interno.
- El ESP32-S3 procesa las lecturas, aplica el diagrama de estados y publica los resultados en el endpoint HTTP GET /datos como JSON.
- Los clientes (GUI Java y app Android) realizan polling HTTP cada 500 ms–1 s en la misma red WiFi local, sin necesidad de internet.

Topología de red:

Red local WiFi 2.4 GHz 802.11n → Router/AP → ESP32-S3 (IP fija asignada por DHCP) → PC/Celular en la misma subred.

16.2 Mensaje final (JSON) con ejemplos reales

El endpoint GET http://<IP_ESP32>/datos retorna un objeto JSON con la siguiente estructura:

Campo | Tipo | Ejemplo | Descripción
"co" | float | 12.50 | Concentración CO en ppm
"no2" | float | 0.031 | Concentración NO₂ en ppm
"co2" | float | 512.0 | CO₂ equivalente en ppm (CCS811)
"voc" | float | 180.0 | TVOC en ppb (CCS811)
"estado" | string | "REPOSO" | Estado del diagrama: REPOSO | ADVERTENCIA | PELIGRO | ALARMA
"t" | long | 12345 | Timestamp en milisegundos desde arranque (millis())

El intercambio de información se realiza mediante mensajes JSON debido a su simplicidad, compatibilidad y bajo consumo de ancho de banda, la ESP32 envía un mensaje de “CO:40.37,NO2:13.159,CO2:415.0,VOC:0.0,EST:ALARMA”, pero lo empaqueta de la siguiente manera.

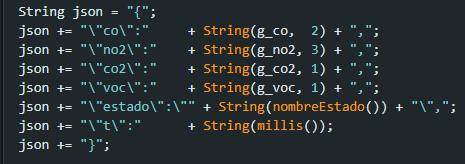
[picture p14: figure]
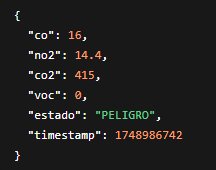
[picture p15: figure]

El cual se vería como el siguiente ejemplo:

Notas sobre el formato:

- co y no2 usan 2–3 decimales para preservar la resolución del ADC de 12 bits.
- co2 y voc usan 1 decimal; el CCS811 entrega valores enteros internamente.
- estado refleja el resultado del diagrama de estados procesado en el firmware.
- t es útil para detectar si el ESP32 se reinició o si los datos son obsoletos.

## 16.3 Frecuencia de envío y justificación (indoor/outdoor)

La frecuencia de muestreo y publicación se definió en 1 segundo (INTERVALO_MS = 1000) con polling del cliente cada 500 ms, por las siguientes razones:

Aplicación indoor (ambiente controlado — laboratorio UCEVA):

- Los gases CO y NO₂ en ambientes interiores varían lentamente (escala de minutos). Un muestreo de 1 s es más que suficiente para detectar tendencias.
- El CCS811 tiene un período de medición interno de 1 segundo (modo de medición 1). Muestrear más rápido no aporta información adicional.
- El servidor HTTP del ESP32-S3 puede manejar múltiples clientes simultáneos sin degradación notable a esta frecuencia.

Consideraciones para aplicación outdoor (si se extiende el proyecto):

- En exteriores con mayor variabilidad (tráfico vehicular, industria), se podría reducir el intervalo a 500 ms para capturar picos transitorios de CO y NO₂.
- A mayor frecuencia, aumenta el consumo energético. Para operación con batería se recomienda modo deep sleep entre lecturas con transmisión cada 5–10 s.
- La frecuencia de polling del cliente puede aumentarse a 200 ms sin impacto significativo en la red local.

## 16.4 Manejo de fallos (reintentos, reconexión, pérdida de datos)

El sistema implementa las siguientes estrategias de tolerancia a fallos:

Reconexión WiFi:

- Si el ESP32-S3 pierde la conexión WiFi, WiFi.status() != WL_CONNECTED es detectado en el loop. Se puede agregar reconexión automática con WiFi.reconnect().
- El servidor HTTP continúa ejecutando server.handleClient() independientemente del estado de las lecturas de sensores.

Fallo del CCS811:

- Si ccs.begin() falla en el setup, la bandera ccsOK = false evita que el loop intente leer el sensor. co2 y voc se mantienen en 0.
- El JSON sigue siendo válido y los demás sensores (CO, NO₂) continúan funcionando.

Timeout HTTP en el cliente:

- HttpReader.java y EspClient.java configuran timeout de conexión y lectura en 2–3 segundos. Si el ESP32 no responde, el cliente muestra “Sin conexión” en la GUI sin bloquear el hilo principal.
- El polling continúa automáticamente en el siguiente ciclo sin intervención del usuario.

Pérdida de datos:

- Al ser polling sin confirmación (fire-and-forget), si un request falla se pierde esa muestra. Para el alcance del proyecto (monitoreo en tiempo real) esto es aceptable.
- El historial de 120 puntos (2 minutos) en la GUI Java permite visualizar tendencias recientes aunque haya caídas momentáneas.
- Para aplicaciones críticas se recomienda agregar almacenamiento en microSD o MQTT con broker local (Mosquitto).

# 17. Dashboard y Visualización

## 17.1 Descripción del tablero (variables, gráficas, filtros por environment)

El sistema cuenta con dos dashboards complementarios: la GUI de escritorio (Java/Swing, NetBeans) y la app móvil Android. Ambos consumen el mismo endpoint JSON del ESP32-S3.

GUI de escritorio — AirMonitorGUI:

- 4 gauges circulares animados (lerp a 60 fps), uno por gas: CO [ppm], NO₂ [ppm], CO₂ [ppm], VOC [ppb].
- Cada gauge muestra: valor numérico con formato adaptativo (0 decimales para CO₂, 3 para NO₂), aguja animada, arco de color dinámico (verde/ámbar/rojo según umbral), marcas de umbral visuales y etiqueta de nivel (✓ NORMAL / △ PRECAUCIÓN / ⚠ PELIGRO).
- 4 gráficas históricas (últimos 120 puntos, 2 minutos) con curva suavizada (Bézier cúbico), relleno degradado y etiqueta del último valor.
- Banner de estado general (REPOSO / ADVERTENCIA / PELIGRO / ALARMA) con color de fondo dinámico.
- Timestamp de última actualización, indicador de conexión y campo de IP configurable.

App Android — Gas Monitor P.I6Def:

- Grid 2×2 de tarjetas de valor en tiempo real con indicador de color (punto verde/ámbar/rojo).
- 4 gráficas LineChart (MPAndroidChart) con últimos 60 puntos, relleno y animación.
- Banner de estado con color de fondo adaptativo.
- Botón de configuración de IP, conexión/desconexión y modo DEMO con datos simulados.
- Sistema de notificaciones push nativas Android por canal (advertencia, peligro, alarma con vibración).

Filtros por environment:

- El campo IP de ambas interfaces permite cambiar el nodo monitoreado en tiempo real, lo que permite alternar entre diferentes ESP32-S3 instalados en distintos ambientes sin reiniciar la aplicación.

## 17.2 Alertas y reglas implementadas

Las alertas se implementan en dos niveles: firmware (ESP32-S3) y cliente.

Nivel firmware — Diagrama de estados:

Gas | Unidad | Rango sensor | Advertencia | Peligro | Norma
CO | ppm | 5 – 5000 | 35 | 200 | NIOSH TWA/STEL
NO₂ | ppm | 0.1 – 10 | 0.5 | 1.0 | NIOSH STEL
CO₂ | ppm | 400 – 8192 | 1000 | 2000 | ASHRAE 62.1
VOC | ppb | 0 – 1187 | 220 | 660 | IAQ índice

Reglas de transición del diagrama de estados:

- REPOSO → ADVERTENCIA: al menos un gas supera su umbral de advertencia.
- REPOSO/ADVERTENCIA → PELIGRO: al menos un gas supera su umbral de peligro.
- PELIGRO → ALARMA: dos o más gases en peligro simultáneamente, O un gas sostenido en peligro por más de 30 segundos.
- Cualquier estado → REPOSO: todos los gases por debajo de sus umbrales de advertencia.

Nivel cliente — GUI Java:

- Color del gauge cambia dinámicamente: verde (normal), ámbar (advertencia), rojo (peligro).
- Etiqueta de nivel visible en cada gauge sin necesidad de acción del usuario.
- Banner de estado con color de fondo: verde (REPOSO), ámbar (ADVERTENCIA), naranja oscuro (PELIGRO), rojo (ALARMA).

Nivel cliente — App Android:

- Notificación push canal ADVERTENCIA (importancia DEFAULT): aparece en la barra de estado.
- Notificación push canal PELIGRO (importancia HIGH): heads-up notification con vibración.
- Notificación push canal ALARMA (importancia MAX): heads-up con patrón de vibración extendido [500ms-200ms-500ms-200ms-500ms] y mensaje de evacuación.
- Las notificaciones se cancelan automáticamente cuando el estado vuelve a REPOSO.

## 17.3 Evidencias (capturas del dashboard)

Nota: Las capturas de pantalla deben insertarse manualmente en este apartado al momento de la presentación del proyecto. Se recomienda incluir:

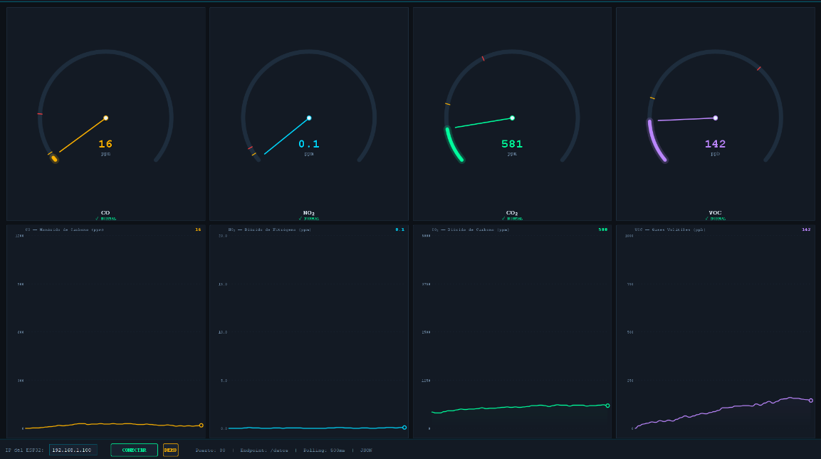
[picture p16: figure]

- GUI Java en estado REPOSO con todos los gauges en verde.

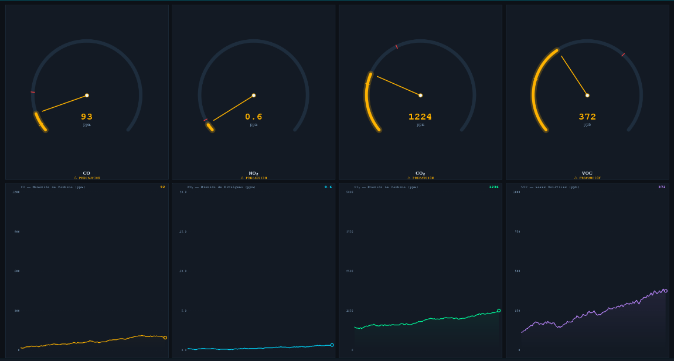
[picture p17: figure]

- GUI Java en estado ADVERTENCIA con gauge de CO₂ en ámbar.

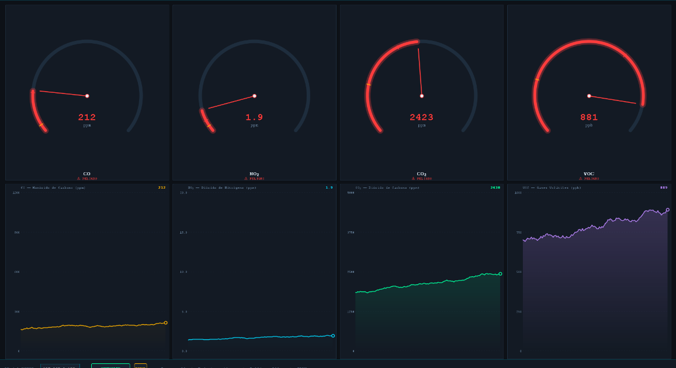
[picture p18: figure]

- GUI Java en estado ALARMA con banner rojo y múltiples gauges en rojo.

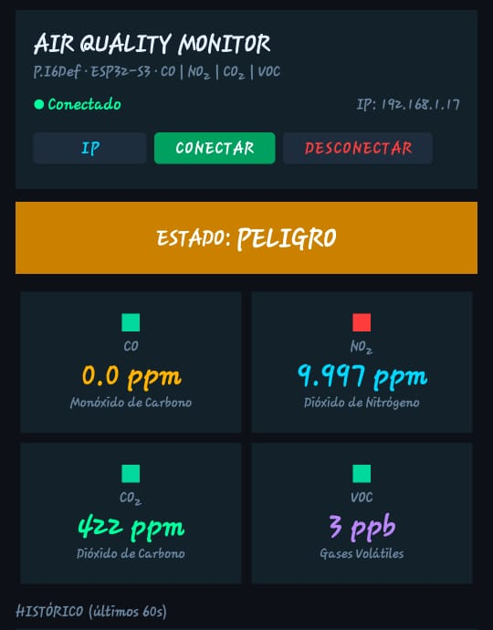
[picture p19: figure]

- App Android mostrando datos en tiempo real.
- Notificación push de ALARMA en el celular.

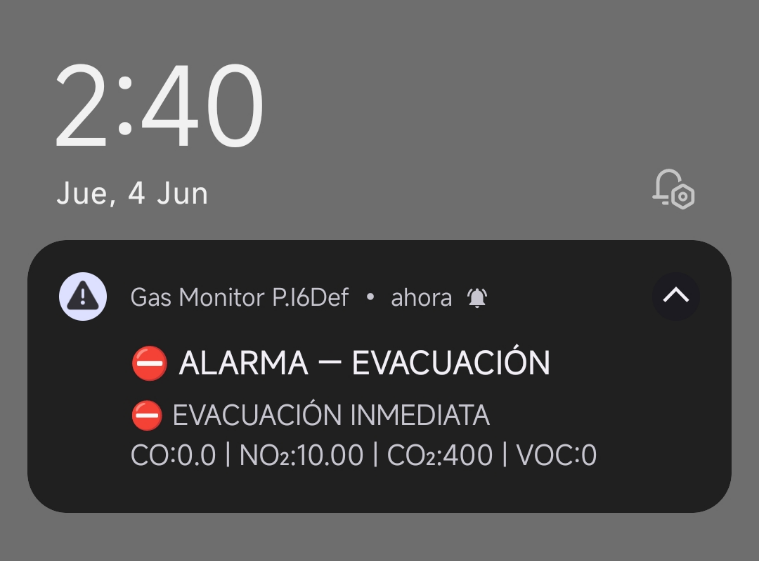
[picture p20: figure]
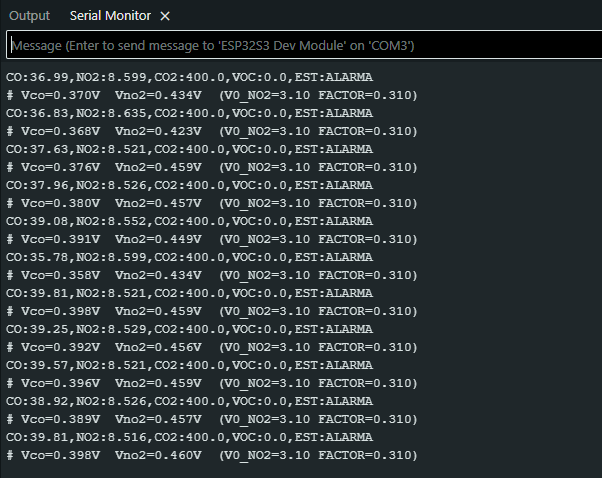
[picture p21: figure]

- Captura del Monitor Serial con voltajes de calibración (Vco y Vno2).

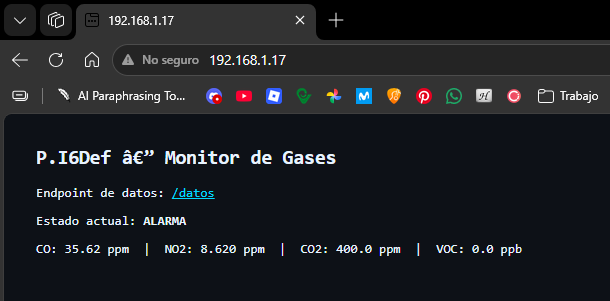
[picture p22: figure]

- Interfaz web del ESP32 (http://<IP>/datos) con JSON en el navegador.

# 18. Calibración y Estimación de Error

## 18.1 Método de calibración (2 puntos o baseline + verificación)

Dado que el proyecto opera en un entorno académico sin acceso a gases de referencia certificados, se adopta el método de calibración por baseline en aire limpio + verificación cualitativa.

GM-702B (SEN0564) — CO (sensor directo):

- Método: calibración de un punto usando el valor de referencia del datasheet Winsen.
- El datasheet indica Vout ≈ 1.50 V a 150 ppm CO en condiciones estándar (20°C, 55% HR).
- Se define V_CO_REF = 1.50 V y CO_REF_PPM = 150 ppm. La conversión es lineal: ppm = (Vout / V_CO_REF) × CO_REF_PPM.
- Verificación: en aire interior normal se espera 0–35 ppm. Valores consistentemente altos indican necesidad de recalibrar V_CO_REF.

GM-102B (SEN0574) — NO₂ (sensor inverso):

- Método: calibración baseline en aire limpio.
- Procedimiento: con el sensor encendido al menos 30 minutos en aire limpio (exterior o ventilación forzada), leer el voltaje Vno2 que imprime el firmware en el Monitor Serial.
- Ese valor se asigna a V0_NO2. El factor de conversión es FACTOR_NO2 = V0_NO2 / 10.0 (para cubrir el rango completo 0–10 ppm).
- La fórmula es: ppm_NO₂ = (V0_NO2 - Vout) / FACTOR_NO2. Si Vout > V0_NO2, se retorna 0 (sin NO₂ detectable).
- Recalibración recomendada: cada vez que el sensor haya estado apagado más de una semana.

CCS811 — eCO₂ y TVOC:

- El CCS811 tiene calibración interna mediante algoritmo propietario de AMS. No requiere calibración externa para uso relativo.
- Burn-in inicial: 48 horas continuas de operación para estabilizar la línea base.
- Warm-up por sesión: 20 minutos antes de confiar en las lecturas. Los valores iniciales (~400 ppm CO₂, 0 ppb TVOC) son valores base del algoritmo, no mediciones reales.

## 18.2 Resultados de calibración

Los siguientes valores fueron establecidos como parámetros de calibración iniciales basados en el datasheet y medición baseline. Deben actualizarse con los valores reales medidos en campo:

Sensor | Parámetro | Valor | Referencia | Método
GM-702B (CO) | V_CO_REF (voltaje a 150 ppm) | 1.50 V (datasheet Winsen) | 150 ppm CO | Punto único
GM-102B (NO₂) | V0_NO2 (voltaje en aire limpio) | Medir en campo (≈ 2.8–3.1 V) | Aire limpio | Baseline
GM-102B (NO₂) | FACTOR_NO2 (V/ppm) | V0_NO2 / 10.0 | Rango 0–10 ppm | Cálculo
CCS811 | Calentamiento inicial | 48 h continuas (primera vez) | Datasheet AMS | Burn-in
CCS811 | Calentamiento por sesión | 20 min antes de confiar en valores | Datasheet AMS | Warm-up

Observación sobre el NO₂:

Durante las pruebas iniciales se detectó una lectura de 15.5 ppm cuando el sensor reportaba 0V de diferencia respecto a V0_NO2 = 3.10 V. Esto indicó que el V0_NO2 configurado era incorrecto (el sensor medía menos de 3.10 V en aire limpio). El firmware fue actualizado para imprimir el voltaje crudo (Vno2=X.XXXV) en el Monitor Serial para facilitar la recalibración en campo.

## 18.3 Presupuesto básico de error (tabla)

Fuente | Gas | Error estimado | Causa | Mitigación
ADC no linealidad | CO, NO₂ | ± 1–2% | ADC ESP32-S3 a 12 bits | Promediado de 4 lecturas
Curva log-log aproximada | CO | ± 15–25% | Linealización de curva del datasheet | Calibración con gas de referencia
Offset V0_NO2 | NO₂ | ± 10–20% | Deriva del valor en aire limpio | Recalibración periódica en campo
Temperatura/Humedad | CO, NO₂ | ± 5–15% | Sensores MOS sensibles a T/H | Compensación con sensor T/H externo
CCS811 warm-up | CO₂, VOC | Alta varianza <20 min | Sensor no estabilizado | Ignorar primeros 20 min de lectura
Latencia HTTP | Todos | < 50 ms (red local) | WiFi + procesamiento | Red local sin internet

Conclusión sobre exactitud:

Para los objetivos del proyecto (detección cualitativa de niveles de contaminación y activación de alertas), la exactitud obtenida es adecuada. Los umbrales de advertencia están definidos con margen suficiente respecto a los umbrales de peligro para absorber el error de medición. Para aplicaciones metrológicas se requeriría calibración con patrones certificados y compensación de temperatura/humedad.

# 21. Repositorio y Guía de Despliegue

## 21.1 Estructura del repositorio

Ruta | Contenido
ESP32_WiFi_Server/ | Firmware Arduino IDE (.ino)
ESP32_WiFi_Server/ESP32_WiFi_Server.ino | Código principal ESP32-S3 + servidor HTTP
Interfaz-gases/src/airmonitor/ | GUI de escritorio Java (NetBeans/Ant)
AirMonitorGUI.java | Ventana principal, lógica de conexión HTTP
HttpReader.java | Polling HTTP al ESP32, parser JSON
GaugePanel.java | Componente gauge circular animado
GraphPanel.java | Gráfica histórica con relleno degradado
SerialReader.java | Lector serial (legacy, no se usa en versión WiFi)
android_app/ | Proyecto Android Studio (Java)
app/src/main/java/com/pi6def/gasmonitor/ | Código fuente Android
ui/MainActivity.java | Actividad principal, gauges, gráficas
network/EspClient.java | Polling HTTP con OkHttp
service/AlertNotifier.java | Notificaciones push por estado
model/GasData.java | Modelo de datos + umbrales
KiCad/P.I6Def/ | Proyecto PCB (esquemático + layout + Gerbers)
Datasheets/ | GM-702B (CO) y GM-102B (NO₂) — Winsen

## 21.2 Cómo compilar y cargar el firmware

### Requisitos previos

- Arduino IDE 2.x instalado.
- Paquete ESP32 de Espressif instalado (Boards Manager → buscar 'esp32' → instalar).
- Librería SparkFun CCS811 instalada (Library Manager → buscar 'SparkFun CCS811').

### Configuración de la placa

Tools → Board → ESP32 Arduino → ESP32S3 Dev Module

- USB Mode: USB-OTG (TinyUSB)
- USB CDC On Boot: Enabled
- Flash Size: 16MB (N16R8) o según tu módulo
- Partition Scheme: Default

### Pasos para cargar

1. Abrir ESP32_WiFi_Server/ESP32_WiFi_Server.ino en Arduino IDE.
2. Editar las líneas de credenciales WiFi:

#define WIFI_SSID "NOMBRE_DE_TU_RED"

#define WIFI_PASS "CONTRASEÑA_DE_TU_RED"

3. Conectar el ESP32-S3 por USB.
4. Si aparece 'Wrong boot mode': mantener presionado BOOT, presionar y soltar RESET, luego soltar BOOT, e inmediatamente dar clic en Upload.
5. Abrir el Monitor Serial (115200 baud). Anotar la IP que aparece:

# [OK] WiFi conectado — IP: 192.168.1.XXX

6. Verificar el endpoint abriendo en el navegador: http://192.168.1.XXX/datos

### Calibración de NO₂ (obligatoria)

7. Con el firmware cargado, en el Monitor Serial observar la línea:

# Vco=0.125V Vno2=X.XXXV (V0_NO2=3.10 FACTOR=0.310)

8. El valor Vno2 en aire limpio es el V0_NO2 real del sensor.
9. Editar en el .ino:

#define V0_NO2 X.XXf // valor medido

#define FACTOR_NO2 X.XXXf // V0_NO2 / 10.0

10. Volver a cargar el firmware.

## 21.3 Cómo visualizar datos en el dashboard (paso a paso)

### GUI de escritorio — Java / NetBeans

11. Abrir NetBeans → File → Open Project → seleccionar carpeta Interfaz-gases.
12. Clic derecho en el proyecto → Properties → Libraries → Add JAR/Folder → seleccionar jserialcomm-2.x.x.jar (descargable de https://github.com/Fazecast/jSerialComm/releases).
13. Clean and Build Project (Shift+F11).
14. Run Project (F6).
15. En el campo 'IP del ESP32' ingresar la IP anotada del Monitor Serial.
16. Presionar CONECTAR o Enter. Los gauges comenzarán a actualizar en ~500 ms.
17. Para modo sin hardware disponible: presionar DEMO para simular datos.

### App Android

18. Abrir Android Studio → File → Open → seleccionar carpeta android_app.
19. Esperar sincronización de Gradle (requiere internet para descargar dependencias).
20. Conectar el celular por USB con Depuración USB activada (Ajustes → Opciones de desarrollador).
21. Asegurarse que el celular está en la misma red WiFi que el ESP32.
22. Run (Shift+F10) o clic en el botón de play en Android Studio.
23. En la app: presionar el botón IP, ingresar la IP del ESP32 → Guardar.
24. Presionar CONECTAR. Los datos aparecerán en ~1 segundo.
25. Para recibir notificaciones: aceptar el permiso de notificaciones cuando la app lo solicite.

### Verificación rápida desde el navegador

Sin necesidad de instalar ninguna aplicación, se puede verificar el funcionamiento del sistema accediendo desde cualquier dispositivo en la misma red WiFi a:

http://<IP_DEL_ESP32>/ → Página web de resumen

http://<IP_DEL_ESP32>/datos → JSON en tiempo real

Esto permite confirmar que el firmware funciona correctamente antes de configurar los dashboards.

# REFERENCIAS BIBLIOGRÁFICAS

Borrego, C., Costa, A. M., Ginja, J., Amorim, M., Coutinho, M., Karatzas, K., ... & Penza, M. (2016). Assessment of air quality microsensors versus reference methods: The EuNetAir joint exercise. Atmospheric Environment, 147, 246–263. https://doi.org/10.1016/j.atmosenv.2016.09.050

Kumar, P., Morawska, L., Martani, C., Biskos, G., Neophytou, M., Di Sabatino, S., ... & Britter, R. (2015). The rise of low-cost sensing for managing air pollution in cities. Environment International, 75, 199–205. https://doi.org/10.1016/j.envint.2014.11.019

Lewis, A., & Edwards, P. (2016). Validate personal air-pollution sensors. Nature, 535(7610), 29–31. https://doi.org/10.1038/535029a

Liu, X., Cheng, S., Liu, H., Hu, S., Zhang, D., & Ning, H. (2012). A Survey on Gas Sensing Technology. Sensors, 12(7), 9635–9665. https://doi.org/10.3390/s120709635

Mead, M. I., Popoola, O. A. M., Stewart, G. B., Landshoff, P., Calleja, M., Hayes, M., ... & Jones, R. L. (2013). The use of electrochemical sensors for monitoring urban air quality in low-cost, high-density networks. Atmospheric Environment, 70, 186–203. https://doi.org/10.1016/j.atmosenv.2012.11.060

Spinelle, L., Gerboles, M., Villani, M. G., Aleixandre, M., & Bonavitacola, F. (2015). Field calibration of a cluster of low-cost available sensors for air quality monitoring. Part A: Ozone and nitrogen dioxide. Sensors and Actuators B: Chemical, 215, 249–257. https://doi.org/10.1016/j.snb.2015.03.031

Zimmerman, N., Presto, A. A., Kumar, S. P. N., Gu, J., Hauryliuk, A., Robinson, E. S., & Robinson, A. L. (2018). A machine learning calibration model using random forests to improve sensor performance for lower-cost air quality monitoring. Atmospheric Measurement Techniques, 11(1), 291–313. https://doi.org/10.5194/amt-11-291-2018

ANEXOS

## A1. Datasheets y Notas Técnicas

Los siguientes documentos técnicos fueron consultados para el diseño y caracterización del módulo:

- SEN0564 (DFRobot CO Sensor — MEMS): https://www.dfrobot.com/product-2646.html
- SEN0574 (DFRobot NO₂ Sensor — MEMS): https://www.dfrobot.com/product-2646.html
- ESP32-S3-WROOM-1U Datasheet (Espressif): https://www.espressif.com/sites/default/files/documentation/esp32-s3-wroom-1_wroom-1u_datasheet_en.pdf
- ESP32-S3 Technical Reference Manual: https://documentation.espressif.com/esp32-s3_technical_reference_manual_en.pdf
- LMV321 Op-Amp Datasheet (TI): https://www.ti.com/lit/ds/symlink/lmv321.pdf
- LP38692MP-3.3 LDO Datasheet (TI): https://www.ti.com/lit/ds/symlink/lp38690.pdf
- REF2033A Voltage Reference Datasheet (TI): https://www.ti.com/product/REF2033
- CCS811 Digital Gas Sensor Datasheet (ScioSense): https://www.sciosense.com/products/environmental-sensors/ccs811-datasheet/

## A2. BOM Actualizada (Lista de Materiales v1 — Pedido Mouser N.° 279751168)

La siguiente tabla refleja los componentes efectivamente adquiridos según la orden de compra Mouser N.° 279751168, enviada el 21 de abril de 2026. Los componentes del pedido son los que se usarán en el PCB definitivo.

Ítem | Ref. Mouser | P/N Fabricante | Descripción | Cant. | Precio unit. (USD) | Estado
1 | 179-TS046685BK160SMR | TS04-66-85-BK-160-SMT-TR | Interruptor táctil 6×6 mm, 8.5 mm, 160 gf, SMD | 5 | $0.046 | Enviado
2 | 594-MCU08050C1002FP5 | MCU08050C1002FP500 | Resistor película fina 10 kΩ, 0.125W, 1%, 0805 | 11 | $0.007 | Enviado
3 | 926-LP38692MP3.3NOPB | LP38692MP-3.3/NOPB | Regulador LDO 1A, 3.3 V, con pin ENABLE, SOT-223 | 2 | $2.11 | Enviado
5 | 356-ESP32S3WM1UN16R8 | ESP32-S3-WROOM-1U-N16R8 | Módulo WiFi/BT, ESP32-S3R8, 8MB PSRAM, 16MB Flash, conector IPEX | 1 | $6.56 | Enviado
6 | 187-CL21A226KOQNNNE | CL21A226KOQNNNE | Capacitor MLCC 22 µF, 16V, X5R, 0805 | 5 | $0.053 | Enviado
8 | 810-C2012X5R1C105K-2 | C2012X5R1C105K085AA | Capacitor MLCC 1.0 µF, 16V, X5R, 0805 | 20 | $0.005 | Enviado
15 | 667-ERA-6APB103V | ERA-6APB103V | Resistor película fina 10 kΩ, 0.1%, 15 ppm, AEC-Q200, 0805 | 12 | $0.25 | Enviado
17 | 667-ERA-6AEB182V | ERA-6AEB182V | Resistor película fina 1.8 kΩ, 0.1%, 25 ppm, 0805 | 10 | $0.054 | Enviado
18 | 667-ERA-6AEB154V | ERA-6AEB154V | Resistor película fina 150 kΩ, 0.1%, 1/8W, 0805 | 10 | $0.054 | Enviado
19 | 667-ERA-6AEB472V | ERA-6AEB472V | Resistor película fina 4.7 kΩ, 0.1%, 1/8W, 0805 | 10 | $0.054 | Enviado
20 | 810-CGA4J3X7R1C155K | CGA4J3X7R1C155K125AB | Capacitor MLCC 1.5 µF, 16V, X7R, AEC-Q200, 0805 | 10 | $0.007 | Enviado
21 | 81-GRM21BZ71C106KE5L | GRM21BZ71C106KE15L | Capacitor MLCC 10 µF, 16V, X7R, 0805 | 10 | $0.01 | Enviado
22 | 306-B4BPHSM4TBLFSN | B4B-PH-SM4-TB(LF)(SN) | Conector JST PH, 4 pines, SMD top | 4 | $0.051 | Enviado
23 | 306-B3BPHKSGW | B3B-PH-K-S-GW | Conector JST PH, 3 pines, THT top | 4 | $0.025 | Enviado
24 | 426-SEN0574 | SEN0574 | Sensor MEMS NO₂, salida analógica, 0.1–10 ppm (DFRobot) | 2 | $2.10 | Enviado
25 | 426-SEN0564 | SEN0564 | Sensor MEMS CO, salida analógica, 5–5000 ppm (DFRobot) | 2 | $1.37 | Enviado
26 | 595-LMV321IDCKT | LMV321IDCKT | Op-Amp rail-to-rail, single, low-voltage, SOT-23-5 | 4 | $0.094 | Enviado
27 | 798-CX90B-16P1 | CX90B-16P1 | Conector USB tipo C, SMD | 2 | $0.129 | Enviado

Nota: Los sensores SEN0574 y SEN0564 corresponden a los módulos breakout DFRobot adquiridos. El sensor digital CCS811 y el LED RGB se obtienen localmente. El costo total del pedido Mouser fue de aproximadamente USD 48 más aranceles de importación colombianos.

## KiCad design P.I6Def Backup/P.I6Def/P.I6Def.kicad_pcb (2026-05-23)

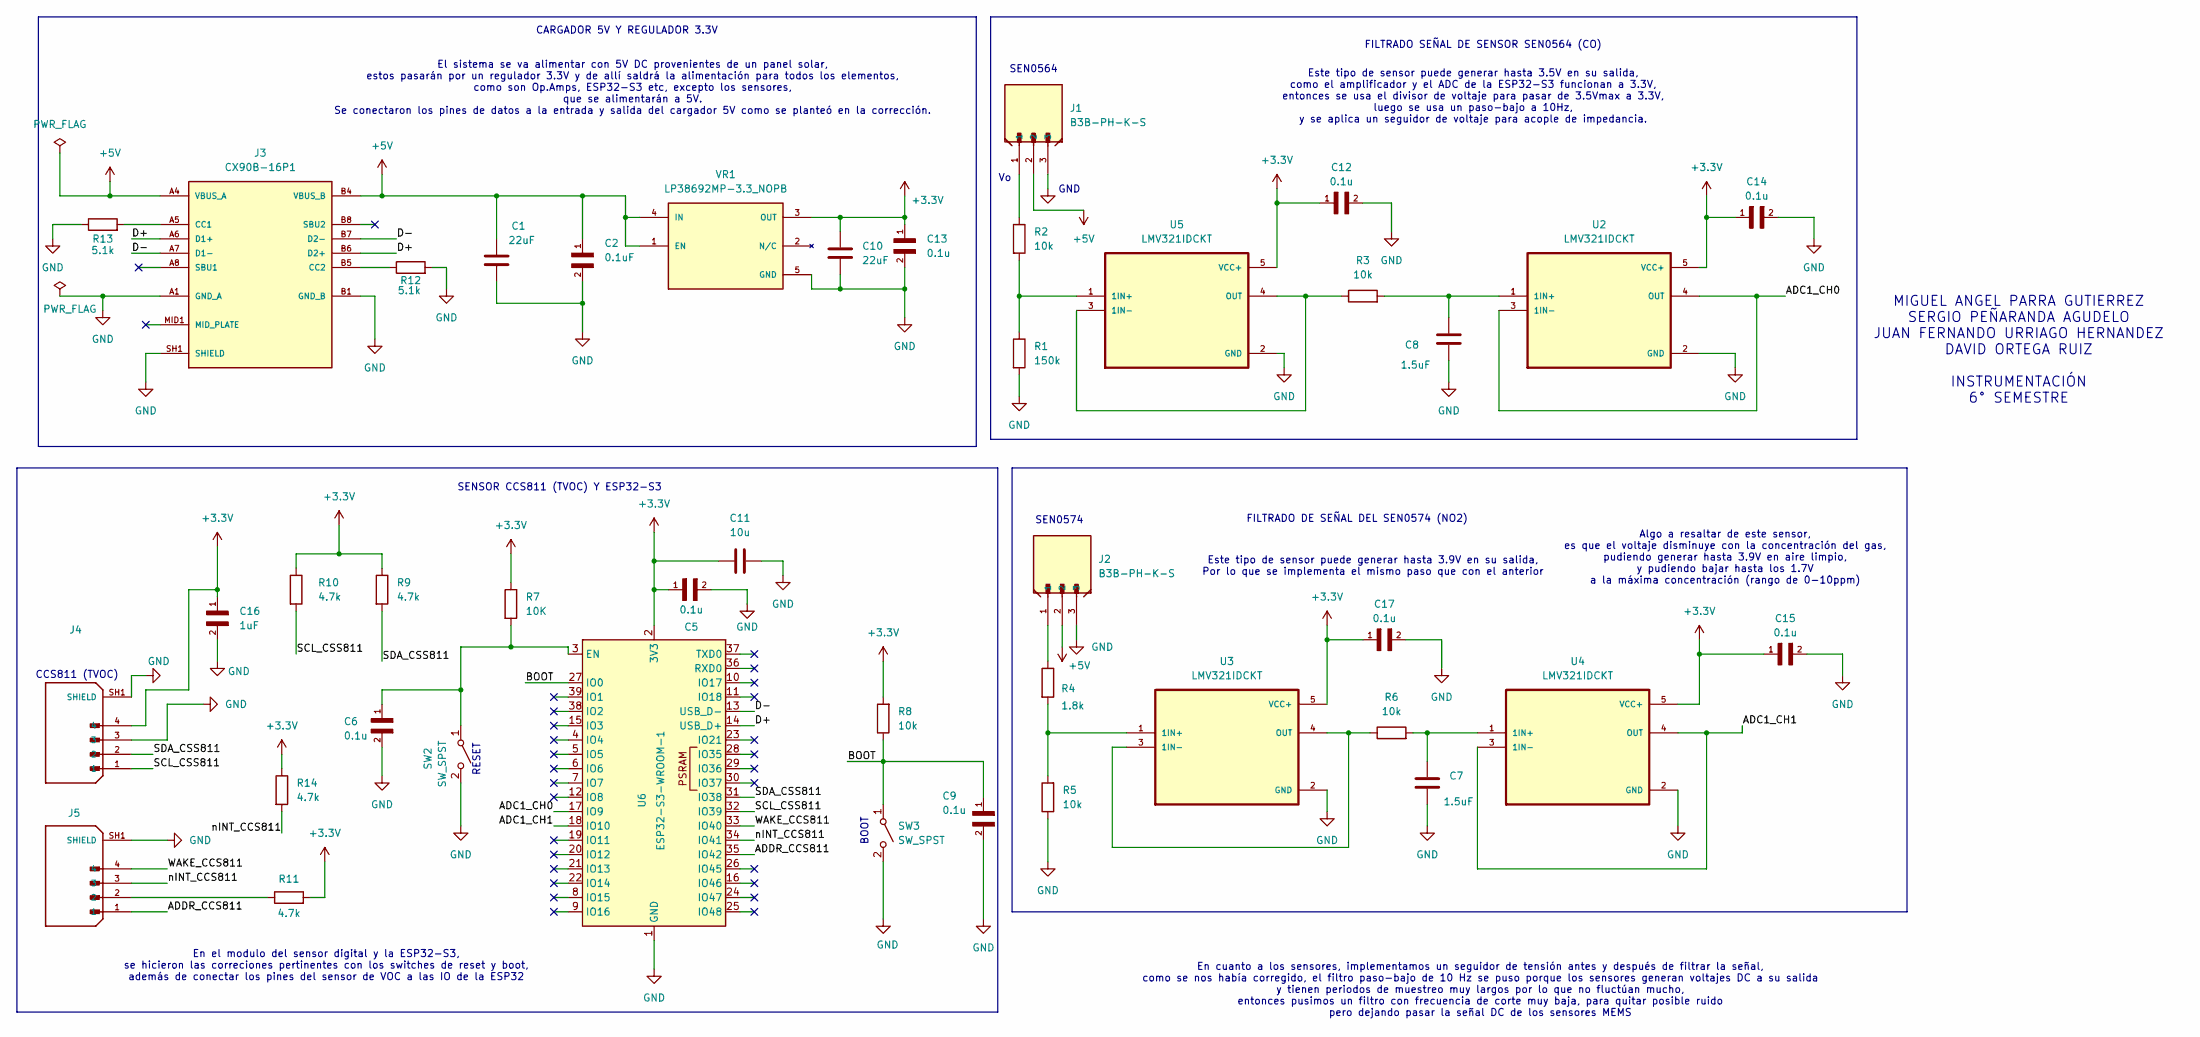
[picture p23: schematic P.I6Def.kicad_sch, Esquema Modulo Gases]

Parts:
C1, C10: 22uF; CAPC2012X140N
C2: 0.1uF; CAPC2012X88N
C5, C6, C9, C12, C13, C14, C15, C17: 0.1u; CAPC2012X88N
C7, C8: 1.5uF; CAPC2012X145N
C11: 10u; CAPC2012X145N
C16: 1uF; CAPC2012X100N
J1, J2: B3B-PH-K-S; JST_B3B-PH-K-S
J3: CX90B-16P1; HIROSE_CX90B-16P1; PARTREV 23.04.05
J4, J5: B4B-PH-SM4-TB_LF__SN__P_; JST_B4B-PH-SM4-TB_LF__SN__P_; PARTREV N/A
R1: 150k; RES_ERA6AEB154V
R2, R3, R5, R6, R8: 10k; RESC2012X55N
R4: 1.8k; RES_ERA6AEB182V
R7: 10K; RESC2012X55N
R9, R10, R11, R14: 4.7k; RES_ERA6AEB472V
R12, R13: 5.1k; RESC2012X55N
SW2, SW3: SW_SPST; SW_TS04-66-85-BK-160-SMT-TR
U2, U3, U4, U5: LMV321IDCKT; SOT65P210X110-5N
U6: ESP32-S3-WROOM-1; ESP32-S3-WROOM-1U
VR1: LP38692MP-3.3_NOPB; SOT150P700X180-5N; PARTREV M

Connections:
+3.3V: C5.1, C10.1, C11.1, C12.1, C13.1, C14.1, C15.1, C16.1, C17.1, J4.4, R7.1, R8.2, R9.1, R10.1, R11.2, R14.1, U2.5 (VCC+), U3.5 (VCC+), U4.5 (VCC+), U5.5 (VCC+), U6.2 (3V3), VR1.3 (OUT)
+5V: C1.1, C2.1, J1.2, J2.2, J3.A4 (VBUS_A), J3.A9 (VBUS_A), J3.B4 (VBUS_B), J3.B9 (VBUS_B), VR1.1 (EN), VR1.4 (IN)
/ADC1_CH0: U2.3 (1IN-), U2.4 (OUT), U6.17 (IO9)
/ADC1_CH1: U4.3 (1IN-), U4.4 (OUT), U6.18 (IO10)
/ADDR_CCS811: J5.1, U6.35 (IO42)
/BOOT: C9.1, R8.1, SW3.1 (A), U6.27 (IO0)
/D+: J3.A6 (D1+), J3.B6 (D2+), U6.14 (USB_D+)
/D-: J3.A7 (D1-), J3.B7 (D2-), U6.13 (USB_D-)
/SCL_CSS811: J4.1, R10.2, U6.32 (IO39)
/SDA_CSS811: J4.2, R9.2, U6.31 (IO38)
/WAKE_CCS811: J5.4, U6.33 (IO40)
/nINT_CCS811: J5.3, R14.2, U6.34 (IO41)
GND: C1.2, C2.2, C5.2, C6.2, C7.2, C8.2, C9.2, C10.2, C11.2, C12.2, C13.2, C14.2, C15.2, C16.2, C17.2, J1.3, J2.3, J3.A1 (GND_A), J3.A12 (GND_A), J3.B1 (GND_B), J3.B12 (GND_B), J3.SH1 (SHIELD), J3.SH2 (SHIELD), J3.SH3 (SHIELD), J3.SH4 (SHIELD), J3.SH5 (SHIELD), J3.SH6 (SHIELD), J4.3, J4.SH1 (SHIELD), J4.SH2 (SHIELD), J5.SH1 (SHIELD), J5.SH2 (SHIELD), R1.2, R5.1, R12.2, R13.1, SW2.2 (B), SW3.2 (B), U2.2 (GND), U3.2 (GND), U4.2 (GND), U5.2 (GND), U6.1 (GND), U6.40 (GND), U6.41 (GND), VR1.5 (GND)
unnamed: J1.1, R2.1
unnamed: J2.1, R4.1
unnamed: J3.A5 (CC1), R13.2
unnamed: J3.B5 (CC2), R12.1
unnamed: J5.2, R11.1
unnamed: C6.1, R7.2, SW2.1 (A), U6.3 (EN)
unnamed: C8.1, R3.2, U2.1 (1IN+)
unnamed: R4.2, R5.2, U3.1 (1IN+)
unnamed: R6.1, U3.3 (1IN-), U3.4 (OUT)
unnamed: C7.1, R6.2, U4.1 (1IN+)
unnamed: R1.1, R2.2, U5.1 (1IN+)
unnamed: R3.1, U5.3 (1IN-), U5.4 (OUT)

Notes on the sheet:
Algo a resaltar de este sensor, es que el voltaje disminuye con la concentración del gas, pudiendo generar hasta 3.9V en aire limpio, y pudiendo bajar hasta los 1.7V a la máxima concentración (rango de 0-10ppm)
SEN0574
MIGUEL ANGEL PARRA GUTIERREZ SERGIO PEÑARANDA AGUDELO JUAN FERNANDO URRIAGO HERNANDEZ DAVID ORTEGA RUIZ INSTRUMENTACIÓN 6° SEMESTRE
RESET
Este tipo de sensor puede generar hasta 3.9V en su salida, Por lo que se implementa el mismo paso que con el anterior
En cuanto a los sensores, implementamos un seguidor de tensión antes y después de filtrar la señal, como se nos había corregido, el filtro paso-bajo de 10 Hz se puso porque los sensores generan voltajes DC a su salida y tienen periodos de muestreo muy largos por lo que no fluctúan mucho, entonces p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
El sistema se va alimentar con 5V DC provenientes de un panel solar, estos pasarán por un regulador 3.3V y de allí saldrá la alimentación para todos los elementos, como son Op.Amps, ESP32-S3 etc, excepto los sensores, que se alimentarán a 5V. Se conectaron los pines de datos a la entrada y salida d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
CARGADOR 5V Y REGULADOR 3.3V
SENSOR CCS811 (TVOC) Y ESP32-S3
FILTRADO SEÑAL DE SENSOR SEN0564 (CO)
SEN0564
Este tipo de sensor puede generar hasta 3.5V en su salida, como el amplificador y el ADC de la ESP32-S3 funcionan a 3.3V, entonces se usa el divisor de voltaje para pasar de 3.5Vmax a 3.3V, luego se usa un paso-bajo a 10Hz, y se aplica un seguidor de voltaje para acople de impedancia.
En el modulo del sensor digital y la ESP32-S3, se hicieron las correciones pertinentes con los switches de reset y boot, además de conectar los pines del sensor de VOC a las IO de la ESP32
GND
CCS811 (TVOC)
FILTRADO DE SEÑAL DEL SEN0574 (NO2)
BOOT

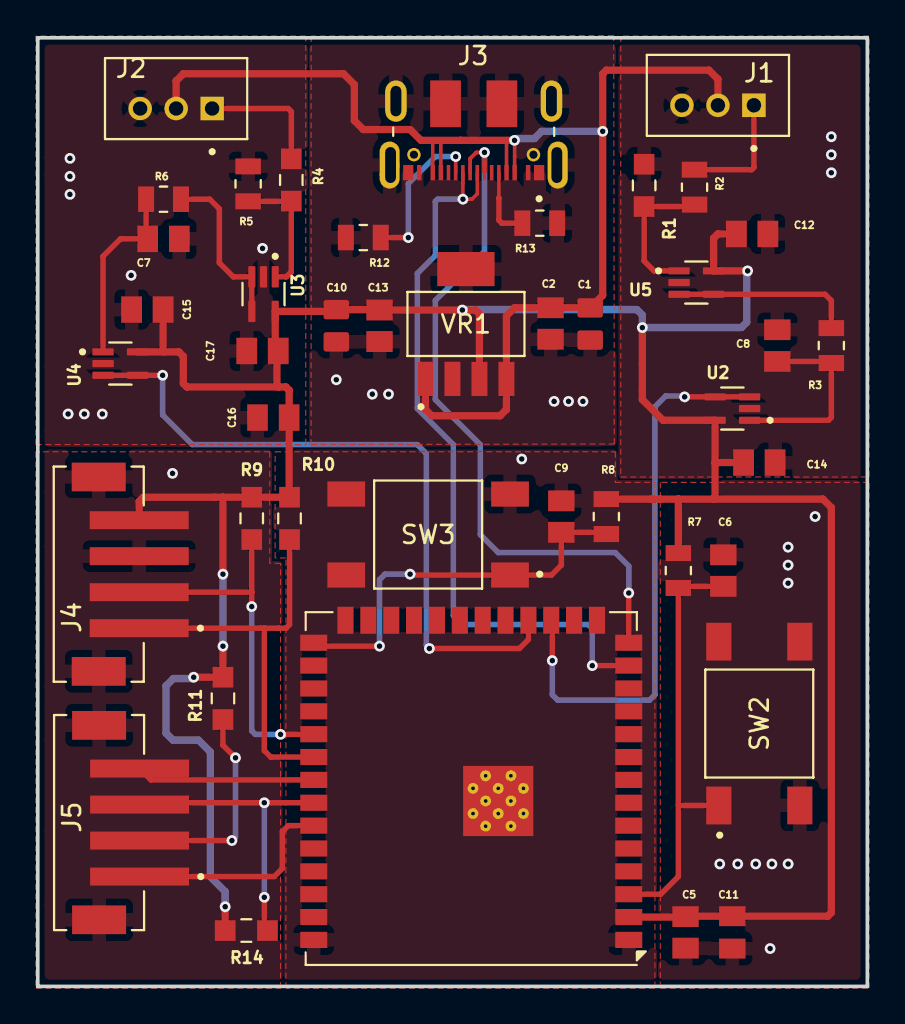
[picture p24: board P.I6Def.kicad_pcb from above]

Board: 2 copper layers, 46.1 x 52.7 mm, 42 parts (0 on the bottom side), 25 nets.

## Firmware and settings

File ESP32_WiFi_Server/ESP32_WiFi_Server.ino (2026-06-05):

/* ============================================================
 *
 *  Mapa de pines:
 *    SDA_CCS811 → GPIO39
 *    SCL_CCS811 → GPIO38
 *    SEN0564 CO  → GPIO17
 *    SEN0574 NO2 → GPIO18
 *
 * ============================================================
 */

#include <Arduino.h>
#include <Wire.h>
#include <math.h>
#include <WiFi.h>
#include <WebServer.h>
#include <SparkFunCCS811.h>

// ─── WiFi ─────────────────────────────────────────────────
#define WIFI_SSID "Familia Urriago" 
#define WIFI_PASS "3113506859"     

// ─── Pines ────────────────────────────────────────────────
#define PIN_SDA 39
#define PIN_SCL 38
#define PIN_CO 17
#define PIN_NO2 18

// ─── ADC ──────────────────────────────────────────────────
#define VREF 3.3f
#define ADC_MAX 4095.0f

// ─── Calibración sensores ──────────────────────────────────
#define CO_REF_PPM 150.0f
#define V_CO_REF 1.50f

// GM-102B (NO2) — sensor INVERSO: Vout BAJA cuando sube NO2
// ──────────────────────────────────────────────────────────
#define V0_NO2 3.10f      
#define FACTOR_NO2 0.31f  

// ─── Umbrales ─────────────────────────────────────────────
#define U_CO_ADV 35.0f
#define U_CO_PEL 200.0f
#define U_NO2_ADV 0.5f
#define U_NO2_PEL 1.0f
#define U_CO2_ADV 1000
#define U_CO2_PEL 2000
#define U_VOC_ADV 220
#define U_VOC_PEL 660

// ─── Diagrama de estados ───────────────────────────────────
typedef enum { REPOSO,
               ADVERTENCIA,
               PELIGRO,
               ALARMA } Estado;
Estado estadoActual = REPOSO;
unsigned long tiempoPeligro = 0;  
#define TIEMPO_ALARMA_MS 30000   

// ─── Servidor HTTP ─────────────────────────────────────────
WebServer server(80);

// ─── Objetos globales ─────────────────────────────────────
CCS811 ccs(0x5A);
bool ccsOK = false;
unsigned long ultimaLectura = 0;
#define INTERVALO_MS 1000

// ─── Valores globales (actualizados en loop) ───────────────
float g_co = 0, g_no2 = 0, g_co2 = 415, g_voc = 0;

// ══════════════════════════════════════════════════════════
//  CONVERSIONES
// ══════════════════════════════════════════════════════════
float rawAV(int raw) {
  return (raw / ADC_MAX) * VREF;
}
float vACO(float v) {
  return v <= 0 ? 0 : (v / V_CO_REF) * CO_REF_PPM;
}
float vANO2(float v) {
  float d = V0_NO2 - v;
  return d < 0 ? 0 : d / FACTOR_NO2;
}

// ══════════════════════════════════════════════════════════
//  DIAGRAMA DE ESTADOS
// ══════════════════════════════════════════════════════════
bool enPeligro(float co, float no2, float co2, float voc) {
  return co >= U_CO_PEL || no2 >= U_NO2_PEL || co2 >= U_CO2_PEL || voc >= U_VOC_PEL;
}
bool enAdvertencia(float co, float no2, float co2, float voc) {
  return co >= U_CO_ADV || no2 >= U_NO2_ADV || co2 >= U_CO2_ADV || voc >= U_VOC_ADV;
}
int gasesEnPeligro(float co, float no2, float co2, float voc) {
  return (co >= U_CO_PEL ? 1 : 0) + (no2 >= U_NO2_PEL ? 1 : 0) + (co2 >= U_CO2_PEL ? 1 : 0) + (voc >= U_VOC_PEL ? 1 : 0);
}

void actualizarEstado(float co, float no2, float co2, float voc) {
  bool pel = enPeligro(co, no2, co2, voc);
  bool adv = enAdvertencia(co, no2, co2, voc);
  int nPel = gasesEnPeligro(co, no2, co2, voc);

  switch (estadoActual) {

    case REPOSO:
      if (pel) {
        estadoActual = PELIGRO;
        tiempoPeligro = millis();
      } else if (adv) {
        estadoActual = ADVERTENCIA;
      }
      break;

    case ADVERTENCIA:
      if (pel) {
        estadoActual = PELIGRO;
        tiempoPeligro = millis();
      } else if (!adv) {
        estadoActual = REPOSO;
      }
      break;

    case PELIGRO:
      if (!pel) {
        estadoActual = adv ? ADVERTENCIA : REPOSO;
        tiempoPeligro = 0;
      } else if (nPel >= 2 || (millis() - tiempoPeligro >= TIEMPO_ALARMA_MS)) {
        estadoActual = ALARMA;
      }
      break;

    case ALARMA:
      if (!pel && !adv) {
        estadoActual = REPOSO;
        tiempoPeligro = 0;
      } else if (!pel) {
        estadoActual = ADVERTENCIA;
        tiempoPeligro = 0;
      }
      break;
  }
}

const char* nombreEstado() {
  switch (estadoActual) {
    case REPOSO: return "REPOSO";
    case ADVERTENCIA: return "ADVERTENCIA";
    case PELIGRO: return "PELIGRO";
    case ALARMA: return "ALARMA";
  }
  return "REPOSO";
}

// ══════════════════════════════════════════════════════════
//  MANEJADORES HTTP
// ══════════════════════════════════════════════════════════
void handleDatos() {
  server.sendHeader("Access-Control-Allow-Origin", "*");

  String json = "{";
  json += "\"co\":" + String(g_co, 2) + ",";
  json += "\"no2\":" + String(g_no2, 3) + ",";
  json += "\"co2\":" + String(g_co2, 1) + ",";
  json += "\"voc\":" + String(g_voc, 1) + ",";
  json += "\"estado\":\"" + String(nombreEstado()) + "\",";
  json += "\"t\":" + String(millis());
  json += "}";

  server.send(200, "application/json", json);
}

void handleRoot() {
  server.sendHeader("Access-Control-Allow-Origin", "*");
  String html = "<html><body style='font-family:monospace;background:#0d1117;color:#e8f4ff;padding:24px'>";
  html += "<h2>P.I6Def — Monitor de Gases</h2>";
  html += "<p>Endpoint de datos: <a style='color:#00d9ff' href='/datos'>/datos</a></p>";
  html += "<p>Estado actual: <b>" + String(nombreEstado()) + "</b></p>";
  html += "<p>CO: " + String(g_co, 2) + " ppm &nbsp;|&nbsp; ";
  html += "NO2: " + String(g_no2, 3) + " ppm &nbsp;|&nbsp; ";
  html += "CO2: " + String(g_co2, 1) + " ppm &nbsp;|&nbsp; ";
  html += "VOC: " + String(g_voc, 1) + " ppb</p>";
  html += "</body></html>";
  server.send(200, "text/html", html);
}

void handleNotFound() {
  server.send(404, "text/plain", "No encontrado");
}

// ══════════════════════════════════════════════════════════
//  SETUP
// ══════════════════════════════════════════════════════════
void setup() {
  Serial.begin(115200);
  delay(500);

  Serial.println(F("\n# P.I6Def — Monitor de Gases con WiFi"));

  // ── CCS811 ────────────────────────────────────────────
  Wire.begin(PIN_SDA, PIN_SCL);
  if (ccs.begin() == false) {
    Serial.println(F("# [ERROR] CCS811 no detectado"));
    ccsOK = false;
  } else {
    Serial.println(F("# [OK] CCS811 listo"));
    ccsOK = true;
  }

  // ── ADC ───────────────────────────────────────────────
  analogReadResolution(12);
  analogSetAttenuation(ADC_11db);

  // ── WiFi ──────────────────────────────────────────────
  Serial.printf("# Conectando a %s", WIFI_SSID);
  WiFi.begin(WIFI_SSID, WIFI_PASS);
  int intentos = 0;
  while (WiFi.status() != WL_CONNECTED && intentos < 30) {
    delay(500);
    Serial.print(".");
    intentos++;
  }
  if (WiFi.status() == WL_CONNECTED) {
    Serial.println();
    Serial.printf("# [OK] WiFi conectado — IP: %s\n",
                  WiFi.localIP().toString().c_str());
    Serial.printf("# Endpoint: http://%s/datos\n",
                  WiFi.localIP().toString().c_str());
  } else {
    Serial.println(F("\n# [ERROR] No se pudo conectar al WiFi"));
  }

  // ── Servidor HTTP ──────────────────────────────────────
  server.on("/", handleRoot);
  server.on("/datos", handleDatos);
  server.onNotFound(handleNotFound);
  server.begin();
  Serial.println(F("# [OK] Servidor HTTP iniciado en puerto 80"));
  Serial.println(F("# ─────────────────────────────────────────"));
}

// ══════════════════════════════════════════════════════════
//  LOOP
// ══════════════════════════════════════════════════════════
void loop() {
  server.handleClient(); 

  unsigned long ahora = millis();
  if (ahora - ultimaLectura >= INTERVALO_MS) {
    ultimaLectura = ahora;

    float vCO = rawAV(analogRead(PIN_CO));
    float vNO2 = rawAV(analogRead(PIN_NO2));
    g_co = vACO(vCO);
    g_no2 = vANO2(vNO2);
    if (ccsOK && ccs.dataAvailable()) {
      ccs.readAlgorithmResults();
      g_co2 = (float)ccs.getCO2();
      g_voc = (float)ccs.getTVOC();
    }

    // Actualizar estado
    actualizarEstado(g_co, g_no2, g_co2, g_voc);

    // Serial — ppm + voltajes crudos para calibración
    Serial.printf("CO:%.2f,NO2:%.3f,CO2:%.1f,VOC:%.1f,EST:%s\n",
                  g_co, g_no2, g_co2, g_voc, nombreEstado());
    Serial.printf("# Vco=%.3fV  Vno2=%.3fV  (V0_NO2=%.2f FACTOR=%.3f)\n",
                  vCO, vNO2, V0_NO2, FACTOR_NO2);
  }
}

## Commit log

2026-04-18 avance footprints
    [P.I.6.kicad_pcb, P.I.6.kicad_sch]
2026-04-25 Adjunto la cotización en Mouser
2026-04-25 Ayuda para subir automaticamente el repositorio
2026-04-25 Descarga Automatica del repositorio para colaboradores
2026-05-08 .bat para descargar repo
2026-05-08 Añado .bat para actualizar Repositorio
2026-05-08 agregue los componentes al pcb
2026-05-08 Interfaz grafica descomprimida
    [P.I.6.kicad_pcb, P.I.6.kicad_sch]
2026-05-12 ACTUALIZACION DE TAMAÑO PCB
    [P.I6Def.kicad_pcb, P.I6Def.kicad_sch]
2026-05-14 MEJORA DE LA PCB
    [P.I6Def.kicad_pcb, P.I6Def.kicad_sch]
2026-05-15 Actualizacion PCB
    [P.I6Def.kicad_pcb, P.I6Def.kicad_sch]
2026-05-18 ACTUALIZACION DE LAS PISTAS DE LA PCB
    [P.I6Def.kicad_pcb]
2026-05-20 terminar conecciones y reorganizar los componentes
    [P.I6Def.kicad_pcb]
2026-05-20 Relleno de Cobre
    [P.I6Def.kicad_pcb]
2026-05-21 Solucion de errores y advertencias de DRC
    [P.I6Def.kicad_pcb]
2026-05-22 fix: correcciones de DRC - falta corregir alivios term y 45grad
    [P.I6Def.kicad_pcb]
2026-05-22 Correcciones planos de tierra
    [P.I6Def.kicad_pcb]
2026-05-23 Creacion de archivos gerber
    [P.I6Def-B_Cu.gbr, P.I6Def-B_Mask.gbr, P.I6Def-B_Paste.gbr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]
2026-05-26 Programacion IDE ESP32-S3 (Primer Versón)
2026-05-29 Adjunto la programacion de la interfaz y ESP32 del ultimo prototipo
    [P.I6Def-B_Cu.gbr, P.I6Def-B_Mask.gbr, P.I6Def-B_Paste.gbr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]
2026-06-02 Correccion de cagada de miguel
    [P.I6Def-B_Cu.gbr, P.I6Def-B_Mask.gbr, P.I6Def-B_Paste.gbr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]
2026-06-04 Creacion de app
2026-06-04 Adjunto la ultima version del PI
    [P.I6Def-B_Cu.gbr, P.I6Def-B_Mask.gbr, P.I6Def-B_Paste.gbr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]
2026-06-04 Actualizacion de documento
2026-06-04 Mejora de la programacion de la ESP32S3
2026-06-04 Archivo de la informacion de la Dashboard
